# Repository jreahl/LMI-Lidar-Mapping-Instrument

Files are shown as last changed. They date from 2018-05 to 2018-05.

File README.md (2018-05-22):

# LMI-Lidar-Mapping-Instrument
A three-dimensional LIDAR scanner built as part of ASTR 202 in Spring 2018 (Wellesley College). 
LMI was built as a scientific instrument on the Scanning Outcrop Rover (ScOut), which is a semi-autonomous, radio-enabled, path-finding rover. ScOut was built in order to explore a bedrock outcrop in the Wellesley Hinterlands, located just west of Lake Waban in Wellesley, Massachusetts. The Rover had two primary scientific objectives: to construct a three-dimensional map of a bedrock outcrop and to collect images of the outcrop surface. The data from the LMI were used to interpret an environment and to create a DEM (digital elevation model) for the path-finding algorithm.

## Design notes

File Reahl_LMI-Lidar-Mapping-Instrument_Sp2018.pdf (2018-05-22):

## LMI: The Lidar Mapping Instrument

Jocelyn Reahl ‘19

ASTR 202: Hands-On Planetary Exploration

May 22, 2018

Prof. Wes Watters

Abstract

The Scanning Outcrop Rover (ScOut) is a semi-autonomous, radio-enabled, path-finding rover that was built during the Spring 2018 semester. ScOut was built in order to explore a bedrock outcrop in the Wellesley Hinterlands, located just west of Lake Waban in Wellesley, Massachusetts. ScOut had two primary scientific objectives: to construct a three-dimensional map of a bedrock outcrop and to collect images of the outcrop surface. Due to time constraints, ScOut was not fully constructed by the end of the semester. However, individual components of this rover were partially or fully complete by the end of this project. This paper focuses on one of the two scientific instruments: the Lidar Mapping Instrument (LMI; pronounced “Lemmy”). LMI constructed a three-dimensional point cloud map using a specialized Lidar scanning mount. These data were used to: 1) interpret an environment and 2) to create a DEM (digital elevation model) for the path-finding algorithm.

## Introduction

Lidar, an acronym for Light Detection and Ranging, is an active form of remote sensing where information about an object is obtained from a signal sent by a transmitter that reflects off of the object and is received back at the source. While there are many types of Lidar, the most common and commercially available Lidar is topographic Lidar, also known as Laser Altimetry for airborne applications. Topographic Lidar sensors use near-infrared (NIR) light in the form of a pulsed laser to measure distances of objects relative to the sensor. These sensors employ the following time-of-flight (ToF) equation to determine the distance D that the object is away from the sensor:

D = tc
2 | (1)

Where t is the elapsed time between sending the laser pulse and recording the backscattered signal, and c is the speed of light (3.0 x 10⁸ m s⁻¹
).
LMI’s Lidar sensor is Garmin’s Lidar Lite v3, which uses a Class 1 NIR laser to measure the distances of objects at a range of up to 40 meters. In LMI’s case, the LIDAR Lite v3 works on an I²C bus under the control of an Arduino Nano microcontroller. A hookup guide for this sensor is available on SparkFun’s website. Finally, the Lidar Lite v3 operates on the Arduino IDE using Garmin’s LIDARLite library (available on GitHub).

This sensor is only able to measure distances; therefore, it is unable to independently construct a three-dimensional point cloud map. In order to construct a map, LMI records three variables in order to record a Lidar measurement in a spherical coordinate system: distance D, azimuth angle q, and altitude angle f. q and f are known using two servo motors, hereby referred to as the azimuth and altitude motors, respectively. A diagram of the relationship between the spherical and Cartesian coordinate systems is shown in Figure 1, and the following equations are used to convert spherical coordinates into Cartesian coordinates:

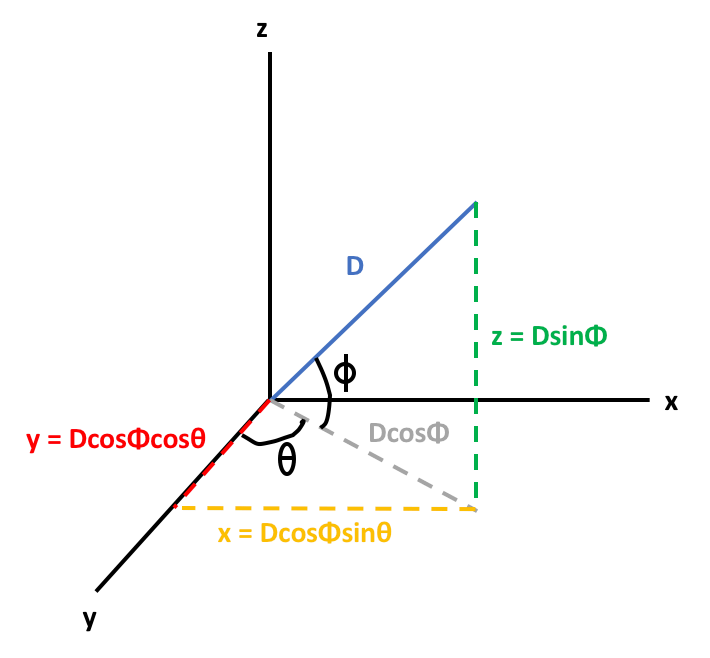
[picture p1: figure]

Figure 1. Diagram of the relationship between spherical and Cartesian coordinates.

x = Dcosφsinθ
y = Dcosφcosθ | (2)
z = Dsinφ

LMI was also meant to be equipped with SparkFun’s MPU 6050 (developed by InvenSense) and SparkFun’s MAG 3110 Triple Axis Magnetometer. However, there was not enough time to integrate these sensors into LMI.

## Instrument Description

LMI uses the following electronic parts: the Lidar Lite v3, a 680 µF capacitor, one standard size servo motor (azimuth servo), one 8 g mini servo motor (altitude servo), an Arduino Nano, a ¼ size Adafruit protoboard, a ½ size Adafruit protoboard, and a 6-wire slip ring. The 6-wire slip ring prevents rotating wires from tangling and disconnecting. The 680 µF capacitor is recommended by Garmin and makes it easier for the Lidar sensor to make measurements. There is room available on the ½ size protoboard to install the MPU 6050 and MAG 3110 sensors in future iterations of this project. There are three male header pins located on the ¼ and ½ size protoboards that accommodate female servo headers. There is also a male header pin soldered to pin A0 on the ½ size protoboard that allows for Parallax Feedback 360°™ functionality. Figure 2 shows a Fritzing diagram of the LMI circuit.
LMI’s Lidar Lite v3 sensor uses a Class 1 NIR laser with a nominal wavelength of 905 nm and an 8 mRadian beam divergence to measure the distances of objects at a range of up to 40 meters. The sensor has an accuracy of ± 2.5 cm between 2 and 5 meters and an accuracy of ± 10 cm at greater than 5 meters. The sensor is able to sample 270 times per second and operates under an I

2
C or pulse width modulation (PWM) interface at a voltage between 4.5 and 6 volts. More information on this sensor can be found in Garmin’s Lidar Lite v3 Manual.

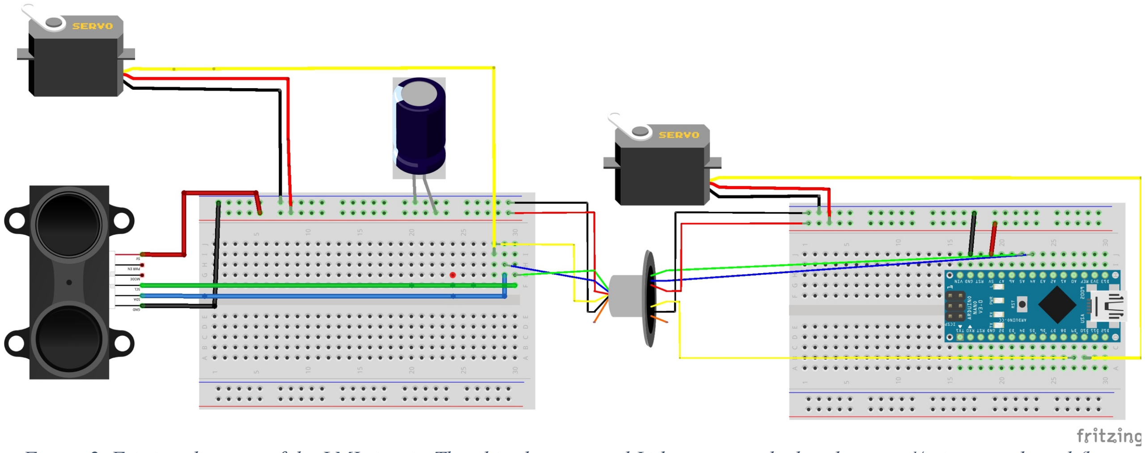
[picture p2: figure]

Figure 2. Fritzing diagram of the LMI circuit. The altitude servo and Lidar are attached to the same ¼ size protoboard (here represented as a ½ size breadboard) with a 680 µF capacitor. The connections on the ¼ size protoboard are then connected to the 6 wire slip ring. The wires from this slip ring are then connected to the Arduino Nano. The azimuth servo is directly connected to the Arduino at digital pin 9 (D9) while the altitude servo is connected via the slip ring at digital pin 10 (D10). The Lidar’s SDA and SCL wires (blue and green, respectively) are connected to the Nano’s analog pins 4 (A4) and 5 (A5), respectively.
The LMI mount was constructed using a combination of laser-cut pieces of plywood and delrin, 3D printed parts, and hot glue. These parts can be found in a variety of formats (SolidWorks, DXF, CDR, and STL) at this project’s associated GitHub repository. Figure 3 shows pictures of the mount assembly and 3D printed parts in SolidWorks. Figure 4 is a photograph of the completed LMI assembly.
The 3D printed parts were printed in Clapp Library’s MakerLab. There were three 3D printed parts: the sensor mount, which secures the Lidar Lite v3 and ¼ size protoboard using screws; the bracket, which suspends the sensor mount in the air and serves as the location where the altitude servo is held in place, and the wirefeed, which allows the gear below the bracket to securely rotate in place while allowing for wires from the slip ring to pass through into the housing’s interior.
The main mount housing was built with laser-cut plywood pieces. Every piece of the housing was held together with hot glue with the exception of the mount base, which was screwed into place. The screws were used to facilitate easy removal and access into the housing’s interior. There are three openings on the housing: a place for the 3D printed wirefeed piece; a place to install a standard-size servo motor; and a place to plug in the micro USB for the Arduino Nano. The wirefeed was hot glued with the gear attached onto the housing. The gears used to rotate the Lidar sensor in the azimuth direction were laser cut out of ¼” white delrin. The bracket was secured to a bracket mount (which was also laser cut and hot glued to a gear) using six screws.

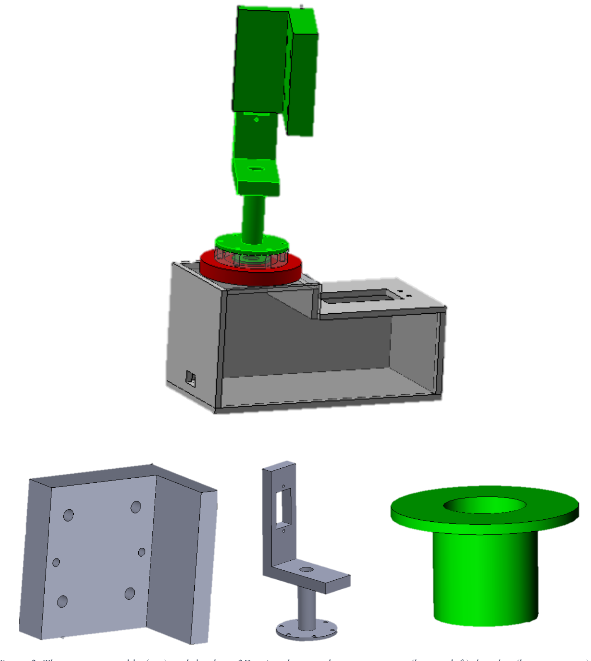
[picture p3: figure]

Figure 3. The mount assembly (top) and the three 3D printed parts: the sensor mount (bottom left), bracket (bottom center), and wirefeed (bottom right).

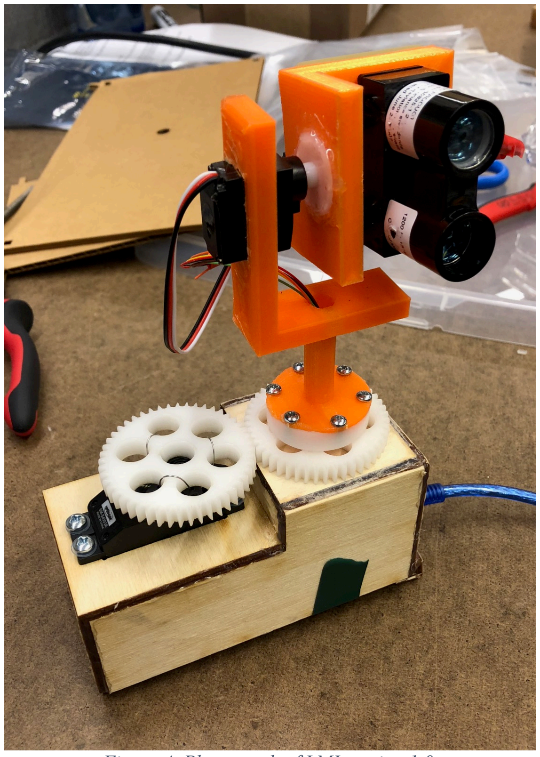
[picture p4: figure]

Figure 4. Photograph of LMI version 1.0.

## Code

The scripts used to operate LMI can be found on this project’s GitHub repository. LMI.ino runs on the Arduino IDE while LidarViewer.pde (by Charles Grassin) runs on Processing. LMI.ino is based on a template called LidarTurret.ino by Charles Grassin, which is also included in the repository. The links to the libraries used in these programs (Servo, LIDARLite, and Wire) can be found in the References section of this paper. To plot LMI’s data, we used Wes Watter’s (2018) cloudplot.py, which constructed not only point cloud maps but also constructed a digital elevation model (DEM) that can be applied to the path-finding algorithm.

## Process and Log

The following is a more streamlined version of LMI’s project log. An informal version, written in bullet point format, can be found as a PDF on this project’s GitHub repository.

1. Received the Lidar Lite v3, MAG 3110 (magnetometer), and MPU 6050 (IMU) from SparkFun and began research on operating specifications. Ordered an Arduino Nano from Amazon.com.

2. Downloaded the Arduino IDE from the Arduino website with the help of a SparkFun tutorial. Also downloaded FTDI drivers so that my Mac OS X High Sierra operating system can use the Arduino IDE.
3. Made my first Arduino circuit using the Lidar Lite v3 Hookup Guide from SparkFun with the following circuit diagram:

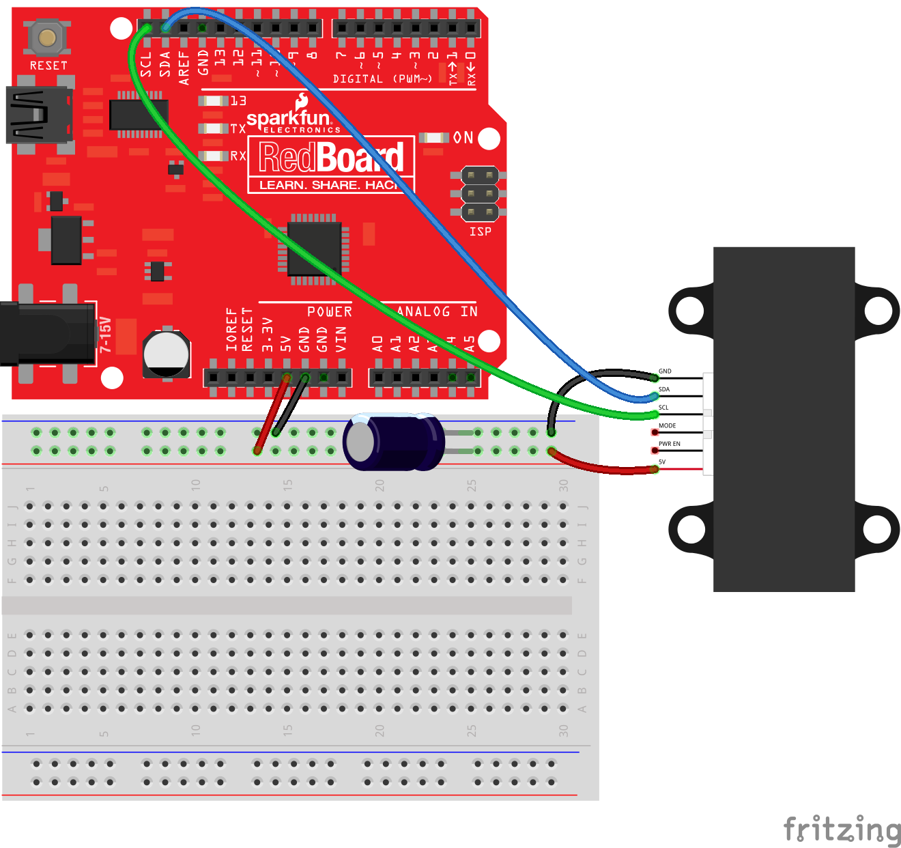
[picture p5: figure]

4. Investigated SLAM algorithms and determined that applying this algorithm would be too complex for the scope of this project. With that being said, it would be interesting to apply these to this instrument in the future.
5. Learned about a program called SlugView, which is a free point cloud analysis software on OpenTopography. However, for our purposes, we realized that using a Python script would also plot our point clouds.
6. Learned about the differences between stepper and servo motors and came to the conclusion that servo motors would be easier to use than stepper motors.
7. Received Arduino Nano from Amazon, but after endless troubleshooting with my computer I realized that the Nano was a clone. In the end I purchased another Nano from the Arduino website.
8. Learned how to solder and began working with the MPU 6050. However, I realized that it wasn’t working given everything that I had tried. Future iterations of this project should investigate how to implement the MPU 6050 into this scanner. Successfully programmed the MAG 3110 but determined that it wouldn’t have much use without the MPU 6050.
9. Ordered a slip ring, continuous rotation servo, Parallax Feedback 360°™ servo, and mini servo.
10. Received all of the previously ordered products and constructed the first LMI prototypes.
11. Designed mount housing in SolidWorks.
12. Laser-cut and 3D printed housing components.
13. Constructed LMI v. 1.0 while simultaneously soldering circuit together on ¼ and ½ size protoboards.
14. Created a scan of the WeLab and of the Outdoor Classroom by the Observatory.

## Preliminary Data

Since the LMI was not installed on the rover, it did not collect data during a “drive” around an outcrop; there was simply not enough time to integrate all of the individual components into the rover. However, LMI was able to complete a trial scan of Wellesley’s Outdoor Classroom, which is located just outside of the Observatory. This location was chosen because it was: 1) nearby and easily accessible, 2) had interesting structures in the field of view (e.g. a tree, a slope), and 3) had randomly distributed rocks that could be used as a proxy for obstacles.
The full scan swept 0 to 75° in f (altitude) and 0 to 180° in q (azimuth). The scan took 25 minutes to complete one whole sweep. The plotted point cloud and DEM are shown in Figure 5. Both plots were created using cloudplot.py (by Wes Watters (2018), available in the repository). All point data recorded as of 5/22/2018, including Test 3 b (the data plotted in Figure 5) are also available in the repository.

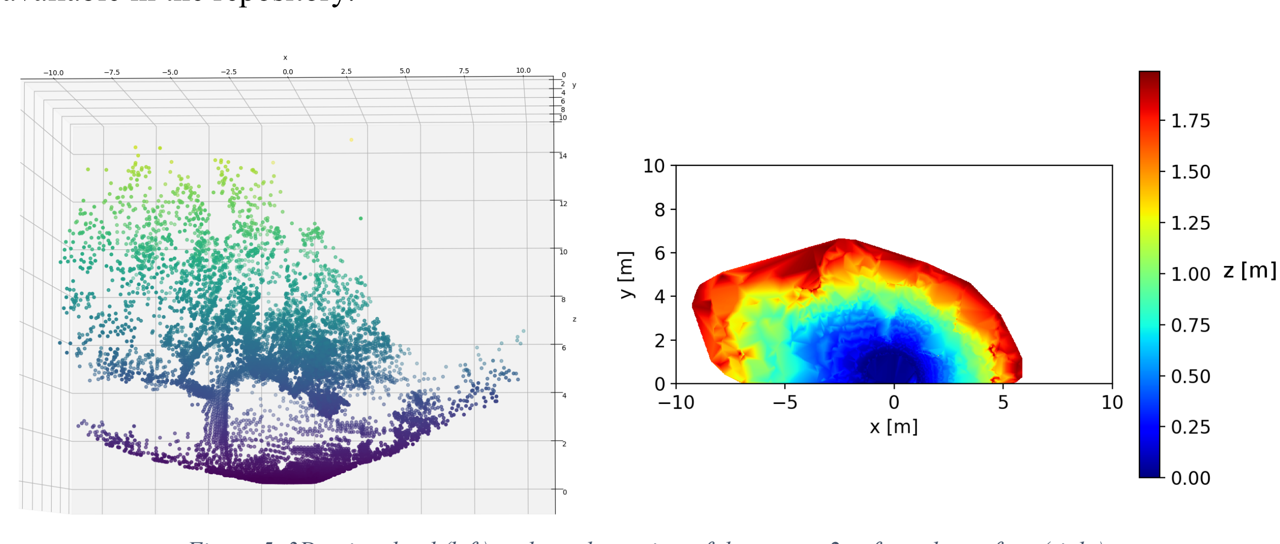
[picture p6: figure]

Figure 5. 3D point cloud (left) and top-down view of the scan < 2 m from the surface (right).

## Discussion and Future Paths

The LMI was able to successfully make multiple scans of both indoor and outdoor structures (the plots in Figure 4 are only one of many more scans). However, the LMI needs to take data during a rover drive. In order to get closer to achieving this goal, future workers need to perform the following tasks, in order of priority:
1. Set up communication between ScOut’s Rasberry Pi and LMI’s Arduino Nano. The Nano should be sending LMI data directly to the RasPi either as a stream of data from the Serial Monitor or as a text (.txt) file that is compiled on the Nano and then sent to the RasPi for processing. This communication also involves setting up the Pi to tell the Nano when to start and stop scans.
2. Implementing the inertial measurement unit (IMU; sensor: MPU 6050) and the magnetometer (sensor: MAG 3110) into the LMI circuit on the ½ size protoboard. The MAG 3110 would operate under the control of the MPU 6050, and the MPU 6050 would send acceleration, gyroscope, orientation, and magnetic bearing data to the Arduino

Nano, which would then be sent to the RasPi. These data act as calibrations that would allow the map to be properly rendered and oriented after multiple scans. Although we were able to get the MAG 3110 to work (using the SparkFun MAG 3110 Magnetometer Breakout Library), we were unable to get the MPU 6050 working after multiple attempts. Links to “starting points” for the MPU 6050 in the form of Arduino forum posts and
I

2Cdev forums can be found in the References section. The issue might potentially lie in how the Arduino addresses the sensor (0 x 68 versus 0 x 69), and there might be a way to easily fix this in Jeff Rowberg’s example code from his MPU 6050 library.
- It is important to note that we were able to control the MAG 3110 sensor independently of the MPU 6050; the final iteration of the MAG 3110 sensor needs to be connected to the MPU 6050. This is another challenge.
- The MAG 3110 also needs to be programmed to record magnetic bearings (e.g. programmed as a compass) instead of raw magnetic field data.
- If the MPU 6050 is a bust, an ADXL 3xx three-axis accelerometer sensor in combination with a three-axis gyroscope sensor would be an acceptable replacement.
3. Implementing the Parallax Feedback 360°™ continuous rotation servo onto the LMI. This servo allows 360° azimuth rotation while simultaneously providing position feedback. This not only allows for full 360° views of the rover’s surroundings, but it would in theory allow our Arduino program to tell the servo (and thereby the Lidar sensor) to move to a specific position that is determined by the direction of the magnetic bearing provided by the MAG 3110 sensor. However, this servo does not have much documentation related to Arduino, as documentation from the website is written in Java. Some Arduino users like JavelinPoint have created code to run this servo, but it relies on PID control and is difficult to use. LMI has an extra header installed at pin A0 in order to allow for easy Parallax Feedback 360°™ installation and use with JavelinPoint’s code.
- An alternative is implementing a stepper motor with a full step size of 0.9°. The advantage of this motor is that it can be programmed to move in smaller than 1 degree increments of q. However, the motor does not provide position feedback unless it has an encoder.
4. Improving the LMI housing and stability, which includes but is not limited to:
- 3D printing the main mount housing (this housing is currently made out of plywood)
- Using wood-joinery techniques to put housing pieces together instead of hot glue.
- Shifting the Lidar sensor position on the altitude servo so that the sensor can move freely from 0 to 180° in altitude (assuming that the Parallax Feedback 360°™ servo or a stepper motor cannot be installed with LMI)
- Purchasing a longer micro-USB to USB cable that can both charge and transmit data. The previously purchased cable is not the right size micro-USB for the Nano.
- Creating more secure wire connections that can still be taken apart (ex. if the LMI needs to be taken apart piece by piece). The current setup has the electronic wiring and the physical mount deeply intertwined; pieces of the physical mount cannot be removed without removing the wires, and vice versa.

## References

LMI GitHub Repository
Reahl, J. LMI-Lidar-Mapping-Instrument, GitHub, accessed May 22, 2018, https://github.com/jreahl/LMI-Lidar-Mapping-Instrument.

Lidar Background
“What is LIDAR?” NOAA, https://oceanservice.noaa.gov/facts/lidar.html.
Corrigan, Fintan. “12 Top LIDAR sensors for UAVs and So Many Great Uses,” DroneZon, January 17, 2018, https://www.dronezon.com/learn-about-drones-quadcopters/best-lidarsensors-for-drones-great-uses-for-lidar-sensors/.
Cameron, Oliver. “An Introduction to LIDAR: The Key Self-Driving Car Sensor,” Voyage, May 9, 2017, https://news.voyage.auto/an-introduction-to-lidar-the-key-self-driving-carsensor-a7e405590cff.
NEON Science. “How Does LiDAR Remote Sensing Work? Light Detection and Ranging,” Youtube, November 24, 2014, https://www.youtube.com/watch?v=EYbhNSUnIdU. Marcoe, K. “LIDAR: an Introduction and Overview,” Portland State University, Fall 2007, http://web.pdx.edu/~jduh/courses/Archive/geog481w07/Students/Marcoe_LiDAR.pdf.

Lidar Mount Examples
TechsOnTube. “LIDAR-Lite v3 – 3D-Scan,” Youtube, November 9, 2016, https://www.youtube.com/watch?v=gCpCGkwwy8I.
Guy, A. “LIDAR Sensor – 3D Printed Rotating Platform – Robotic Vehicle #8,” Youtube, March 10, 2017, https://www.youtube.com/watch?v=RHPAJ3kjc3Q.
Guy, A. “Rotating 360 LIDAR Scanner – 3D Printed up and down scanning – Robotic Vehicle #9,” Youtube, May 6, 2017, https://www.youtube.com/watch?v=zizrY-cOS9k.
Grau, A. “DIY 360 DEGREE REALTIME OUTDOOR LIDAR WITH ROS SUPPORT (GRAULIDAR),” Don’t worry be creative, 2015, http://grauonline.de/wordpress/?page_id=1233.
Grassin, C. “3D LIDAR SCANNER,” Charles’ Labs, October 10, 2017, http://www.charleslabs.fr/en/project-3D+Lidar+Scanner.

Product Pages
Garmin Lidar Lite v3, SparkFun, https://www.sparkfun.com/products/14032. SparkFun Triple Axis Accelerometer and Gyro Breakout – MPU-6050, SparkFun, https://www.sparkfun.com/products/11028.
SparkFun Triple Axis Magnetometer Breakout – MAG3110, SparkFun, https://www.sparkfun.com/products/12670.
Arduino Nano, Arduino, https://store.arduino.cc/usa/arduino-nano. Adafruit Perma-Proto Quarter-sized Breadboard PCB – 3 Pack!, Adafruit, https://www.adafruit.com/product/589.
Adafruit Perma-Proto Half-sized Breadboard PCB – 3 Pack!, Adafruit, https://www.adafruit.com/product/571.
Slip Ring with Flange – 22mm diameter, 6 wires, max 240 V @ 2A, Adafruit, https://www.adafruit.com/product/736.
Servo – Generic (Sub-Micro Size), SparkFun, https://www.sparkfun.com/products/9065.

Servo – Generic High Torque Continuous Rotation (Standard Size), SparkFun, https://www.sparkfun.com/products/9347.
Servo – Generic High Torque (Standard Size), Sparkfun, https://www.sparkfun.com/products/11965.
Parallax Feedback 360° High Speed Servo, Parallax Inc., https://www.parallax.com/product/900-00360.

Software
Arduino Libraries. Servo Library for Arduino, GitHub, accessed May 22, 2018, https://github.com/arduino-libraries/Servo.
ESP8266 Community Forum. Wire.h, GitHub, accessed May 22, 2018, https://github.com/esp8266/Arduino/tree/master/libraries/Wire.
Garmin International. LIDAR-Lite v3 Arduino Library, GitHub, accessed May 22, 2018, https://github.com/garmin/LIDARLite_v3_Arduino_Library.
Arduino IDE 1.8.5, Arduino, https://www.arduino.cc/en/Main/Software.
Processing 3.3.7, Processing, https://processing.org/download/.
Rowberg, J. MPU 6050 Arduino Library, GitHub, accessed May 22, 2018, https://github.com/jrowberg/i2cdevlib/tree/master/Arduino/MPU6050.
SparkFun Electronics. SparkFun MAG3110 Breakout Board Arduino Library, GitHub, accessed May 22, 2018,
https://github.com/sparkfun/SparkFun_MAG3110_Breakout_Board_Arduino_Library. Fritzing 0.9.3b, Fritzing, http://fritzing.org/download/.
I2CScanner, Arduino,
https://playground.arduino.cc/Main/I2cScanner?action=sourceblock&num=1. Grassin, C. LidarTurret.ino, Charles’ Labs, October 10, 2017, http://www.charleslabs.fr/en/project-3D+Lidar+Scanner.
Grassin, C. LidarViewer.pde, Charles’ Labs, October 10, 2017, http://www.charleslabs.fr/en/project-3D+Lidar+Scanner.

LIDAR Lite v3
“Lidar Lite v3 Operation Manual and Technical Specifications,” Garmin International, https://static.garmin.com/pumac/LIDAR_Lite_v3_Operation_Manual_and_Technical_Specificat ions.pdf.

MPU 6050
“MPU-6000 and MPU-6050 Product Specification Revision 3.4,” InvenSense Inc., August 19, 2013, http://43zrtwysvxb2gf29r5o0athu.wpengine.netdna-cdn.com/wpcontent/uploads/2015/02/MPU-6000-Datasheet1.pdf.
“Arduino Playground: MPU-6050 Accelerometer + Gyro,” Arduino, https://playground.arduino.cc/Main/MPU-6050#intro.
Sanjeev, A. “How to Interface Arduino and the MPU 6050 Sensor,” Maker Pro Beta, https://maker.pro/arduino/tutorial/how-to-interface-arduino-and-the-mpu-6050-sensor. Arduino Forum Topic: mpu6050 problem, Arduino, thread started January 13, 2013, http://forum.arduino.cc/index.php?topic=142490.0.

Arduino Forum Topic: Easily Changing I2C Address Of MPU6050 Accelerometer + Gyroscope, Arduino, thread started July 14, 2014, https://forum.arduino.cc/index.php?topic=255033.0.
Rowberg, J. “MPU-6050 6-axis accelerometer/gyroscope,” I

2Cdevlib,
https://www.i2cdevlib.com/devices/mpu6050#help.
“Wiring the MPU 6050 Sensor Mems Accelerometer GYRO,” 14Core, http://www.14core.com/wiring-the-mpu-6050-sensor-accelerometer-gyro-with-nano/.

Parallax Feedback 360°™
Arduino Forum Topic: Controlling Parallax Servo 360 in a certain angle, Arduino, thread started December 13, 2017, https://forum.arduino.cc/index.php?topic=516986.0.

Tutorials
b_e_n. “Installing Arduino IDE,” SparkFun, https://learn.sparkfun.com/tutorials/installingarduino-ide.
Smith, P. “How to Install FTDI Drivers: Mac,” SparkFun, https://learn.sparkfun.com/tutorials/how-to-install-ftdi-drivers/mac.
Hymel, S. “LIDAR-Lite v3 Hookup Guide,” SparkFun, https://learn.sparkfun.com/tutorials/lidar-lite-v3-hookup-guide.
b_e_n. “What is an Arduino?” SparkFun, https://learn.sparkfun.com/tutorials/what-is-anarduino.

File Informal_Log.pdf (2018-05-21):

3/16/2018
- Got the LIDAR-Lite v3 sensor! Hooray! (Also got the MPU-6050 (Accelerometer/Gyroscope) breakout board and the MAG-3110 (Magnetometer) breakout board)
- Catherine is letting me use her Arduino until I can get an Arduino of my own
- I NEED TO ORDER AN ARDUINO (either a nano or an uno; probably an uno tbh but we’ll see)
- Verified that the LIDAR-Lite v3 does the following:
- Does NOT have an attached accelerometer or gyroscope (hence why we needed that accelerometer)
- Uses an I2C or PWM Interface (we’ll be running I2C on an Arduino; it’s what the other sensors use, too)
- Only measures distance measures using a ToF (Time of Flight) measurement: (time between sending signal and receiving) * (speed of light)/2
■ Does nothing else, that’s it’s data format
- Comes with a lovely set of rainbow wires that have their own uses:
■ Red = power source (AREF port)
■ Orange = Power enable (Internal pull-up)
■ Yellow = Mode control
■ Green = I2C SCL
■ Blue = I2C SDA
■ Black = Ground (-) (GND)
- Made a “LIDAR-Lite v3 Safety and Warranty Considerations” doc
- Planning on using this as a non-paper reference for warranty info, and also as a safety reference for eventual “Safety and Booting Protocols” related to the LIDAR sensor
- Main safety takeaways:
■ The sensor uses a Class 1 laser, meaning that it’s safe to look at but we really shouldn’t look directly into where the laser is coming from while it’s on
■ We need to turn it off when we’re not using it, to minimize the risk of hurting our eyes
- Learned what SDA and SCL stands for, and how that relates to I2C format
- Have read to the “Settings” subheading in the “Operational Information” section of the LIDAR-Lite v3 Operator’s Manual
- Need to read further
- Uploaded LIDAR-Lite v3 Operator’s Manual PDF into LIDAR folder in Rover Team Drive
- Uploaded I2C Specifications (version 2.1, January 2000, Phillips) into LIDAR folder
- Downloaded Arduino IDE onto Mac running MacOS High Sierra (v10.13.3) using SparkFun tutorial (https://learn.sparkfun.com/tutorials/installing-arduino-ide) and downloaded Arduino IDE from Arduino website (https://www.arduino.cc/en/Main/Software)

- Downloaded FTDI USB Serial drivers (so I can actually run an Arduino on my Mac) from SparkFun (see following link: https://learn.sparkfun.com/tutorials/how-to-install-ftdi-drivers/mac)
- Successfully downloaded FTDI drivers!
- Had an issue where I thought that the FTDI drivers weren’t working, but it turned out that the USB switch power cable that I was using to connect my USB power + data cable was just giving my computer a power input, which was not what I wanted if I wanted to code on the Arduino
- Successfully communicated with the Arduino using the “Blink” Example (File > Examples > 1. Basics > Blink)!

3/20/2018:
- Got two 680µF capacitors yesterday from Chloe, so no worries about ordering these capacitors
- We’ll be applying these capacitors to our intro LIDAR sensing circuit
- Set up LIDAR circuit according to the below configuration:
- IT WORKED, WE GOT DISTANCE MEASUREMENTS!!! Easy peasy

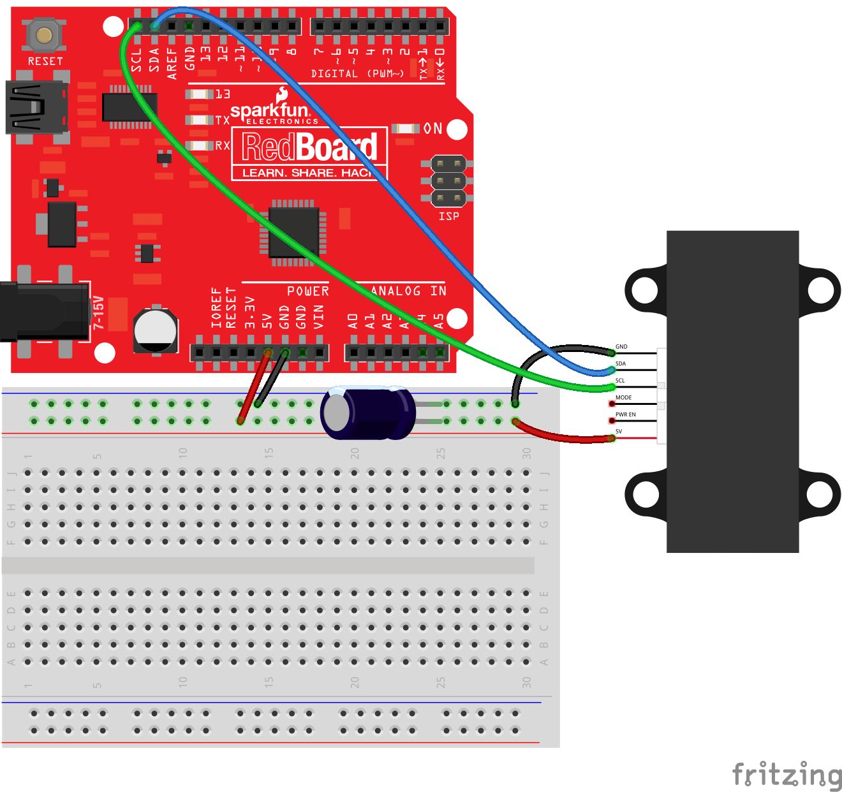
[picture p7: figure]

- Started looking into how we’re gonna visualize these point data using a program
- Questions asked:
■ How do we get these measurements in xyz? Do we use the IMU? ■ How do we take these converted xyz data and turn them into a point cloud?
■ How will these data be used to influence the rover’s movements?
- Started looking into SLAM (Simultaneous Localization and Mapping) algorithms and learning about that
- Realized that just relying on the altitude and azimuth angles relative to a starting point are not gonna be enough if we want to determine xyz points WHILE WE’RE ALSO MOVING BETWEEN MEASUREMENT LOCATIONS (which is why we’re looking into SLAM)

- 3D SLAM algorithms seem to be developing (but compared to 2D versions it seems a little more basic)
- Learned that we’re gonna want to hook up are IMU to be moving with the sensor so we know where the sensor is in 3D space when it’s scanning, which we can then use to determine where the measured data points are relative to the scanner (we’re still looking into SLAM because SLAM allows us to cleanly integrate the scanned map into one cohesive map, instead of individual maps taken at different points that we would then need to blend together, which could end up going horribly wrong especially if we don’t know the scanned area)
- Watched the following videos:
- https://www.youtube.com/watch?v=OJNNm6iMOKk - hour-long talk that gives a really good overview of LIDAR in terms of self-driving robots (which is very necessary for Elif’s part of the project)
■ Also provided info on SLAM and how to plot point clouds
- https://www.youtube.com/watch?v=RHPAJ3kjc3Q - some guy’s first version of a 360° scanning mount, which is good because he actually discusses the pros and cons of this mount; however, he doesn’t show what data is coming from it, and how he might program that
■ Interestingly he uses a reflectance sensor in order to reset the scanner to a starting position, but it means that it doesn’t scan very smoothly :(
■ This version with gears is LOUD
■ Slip rings are IMPORTANT if we want this thing to work at all
- https://www.youtube.com/watch?v=zizrY-cOS9k - the same guy’s second version of his 360° scanning mount, but this time with a weird servo add on so it can go up and down as well as spin in 360° (that being said it didn’t get that much movement so who’s to say how effective it really was)
■ He switches from gears to a timed belt system, which is a heck of a lot smoother and less noisy (and the same kind as used in this more showy, but less useful video: https://www.youtube.com/watch?v=gCpCGkwwy8I) ■ Servo is very awkward because it’s moving the whole platform up and down
■ The whole thing is jumping around a lot because it’s resetting to a known location using the reflectance sensor at every rotation, so it stops and starts again

3/21/2018:
- Found an interesting and free point cloud analysis software called SlugView (“Slug” because it’s from UC Santa Cruz - go Banana Slugs!) that’s listed on OpenTopography, which is a NSF-funded data facility that is available to support PI’s and projects that use lidar
- Link to OpenTopography: http://www.opentopography.org/
- Link to OpenTopography Tools webpage, which includes SlugView: http://opentopo.sdsc.edu/tools/listTools

■ OpenTopography SlugView description: http://opentopo.sdsc.edu/tools/viewTool?toolId=613
- SlugView Description: “This is a Point Cloud visualization tool developed in conjunction with the University of Santa Cruz. SlugView started out as a general point cloud viewer. Neva Ridge Technologies added numerous capabilities primarily to support visualization of point clouds with associated numeric attributes. The data can have up to 2 associated attributes which can be used to control which points are actually displayed. Multiple point clouds can be displayed at once and can be displayed sequentially as an animation. Input data formats are primarily text files. Each line in the text file would contain X, Y, Z and optionally red, green, blue, and additional attribute values.”
- Windows, Mac, and Linux operating systems (needs Java 8, Open GL)
- Manual is listed here:
https://websites.pmc.ucsc.edu/~seisweb/SlugView/manual/manual .html (https://websites.pmc.ucsc.edu/~seisweb/SlugView/manual/manual.html)
- Looks like SlugView can be run in the CLI or in MATLAB, at least according to the manual
- SlugView download and project page: https://websites.pmc.ucsc.edu/~seisweb/SlugView/Slugview.html
- While scrolling through OpenTopography’s website, I found that they hold workshops (which I can’t attend) on how to use lidar and other 3D mapping technologies. This was important because it introduced me to a new potential fix to our 3D mapping issue if we’re given multiple pieces of data at different positions around something: Structure from Motion (SfM)
- SfM is “a photogrammetric range imaging technique for estimating three-dimensional structures from two-dimensional image sequences that may be coupled with local motion signals” (https://en.wikipedia.org/wiki/Structure_from_motion)
■ “Local motion signals” could maybe be acquired through an accelerometer or IMU unit located on the rover body
- Only seems to be a thing for images, so we could potentially apply it to stereo cameras on mast and then the 3D images could be mapped over LIDAR scans, but it doesn’t seem to be relevant to LIDAR point clouds
- Looked into the differences between Stepper and Servo motors:
- Servo motors would allow us to smoothly move over a specific distance (in degrees if we’re using a rotational actuator), and then to return to a home position, and repeat that same thing
■ Typically these move in 180°-ish degrees, but you can buy special ones for 360° motion

■ Controlled with a specific type of pulse train signal: pulses occur at 20mSec (50 Hz) interval, and vary between 1 and 2 mSec in width. Uses PWM (Pulse Width Modulation) hardware (found on many microcontrollers); @ center of mechanical range when pulse = 1.5 mSec ■ Has low RPM (60 RPM max) so stepping motors are better for discrete movements (ie. alt movement on our LIDAR sensor)
■ Used this video to get an understanding of what a servo motor is (Titled “Servo Basic Concepts” from Yasakawa America’s Youtube Channel): https://www.youtube.com/watch?v=t0dSaugIXF8
- This explanation was albeit for industrial users but its still informative for the basic process, and distinguishes between linear and rotational actuators
■ This video (“Electronic Basics #25: Servos and How to Use Them” GreatScott!) is a bit more accessible for someone who’s only planning on using tiny, cheap servos for my project: https://www.youtube.com/watch?v=J8atdmEqZsc
■ Needs a driver to run
■ Have a three-pin plug: ground, voltage, and the command line (pin colors are not consistent across servos, so need to check documentation)
- Stepper motors can easily move in 360° and can easily move at specific degree increments
■ Looked at this video (“Electronic Basics #24: Stepper Motors and How to Use Them” GreatScott!) to get a sense for stepper motors and how to use them: https://www.youtube.com/watch?v=bkqoKWP4Oy4
■ Can be combined with a timing belt to get really smooth motion
■ Needs a driver to run, which can be purchased on SparkFun
■ While you can buy steppers that have 200 or 400 steps per rotation, you can increase the number of steps by half-stepping or micro-stepping which gives you less torque as you increase the number of steps
- In my endless search to figure out my xyz points given just a distance measurement, I decided to look into how I might get these data
- Originally I’m thinking that I should use an IMU sensor that’s actually moving with the moving sensor so that we get acceleration and gyroscope data

4/6/2018:
- Ok so since writing in this last I have:
- Received an Arduino Nano, but upon closer inspection it might be a clone
- Written a detailed update to the LIDAR section of my proposal
■ Compiled scan time estimates assuming the sweep of phi = 45 degrees ■ Figured out calculating relative distance using a reference point
■ Figured out how to calculate xyz points given theta, phi, and distance data ■ All this is effectively written in the proposal
- Still having issues getting Arduino Nano to upload a code

- Downloaded another FTIR driver for Mac (v. 2.4.2) - didn’t work
- Consulted forums - didn’t give me progress
- In exasperation I tried running the Blink example (Arduino > File > Examples > 1. Basics > Blink) on the original Uno that Catherine gave me, and I got the following error:
- /Users/jocelynreahl/Library/Arduino15/packages/arduino/tools/avr-gcc/4.9.2-atme l3.5.4-arduino2/bin/avr-g++: no such file or directory
- Decided to uninstall Arduino software in an attempt to fix it because I couldn’t find the Arduino15 file in the Library on my computer (Macbook Pro running OS X High Sierra)
- Wes and I tried doing a bunch of stuff on the terminal and it… didn’t work. None of it worked
- Started to give up and log into a computer running Windows 7 to try downloading Arduino IDE on it, but realized that when I originally uninstalled the Arduino IDE, I forgot to delete the hidden Arduino15 file in Library
- Had Wes delete it before I redownloaded the new IDE, and IT WORKED HOLY CRAP
■ By “it worked” I mean that the UNO is working on it again; the nano (which I’m certain is a clone now) still isn’t working
- Tried downloading Arduino IDE on classroom computer, and it wouldn’t let me unless I was an admin, so in theory I could log in under Wes’s profile, but that starts getting into some weird territory that requires a lot of effort on both ends
- Ended up just having Jenny get an original Nano from the Arduino website, because nothing seems to be working and the following forum post implies that even if I did install the correct drivers for the clone, it still wouldn’t work on Mac OS Sierra and above unless I did some crazy troubleshooting that is super time consuming -
https://arduino.stackexchange.com/questions/34775/arduino-nano-not-visible-in-s erial-ports-mac-os (https://arduino.stackexchange.com/questions/34775/arduino-nano-not-visible-in-serial-ports-mac-os)
- Got Jenny to get the Nano from this website: https://store.arduino.cc/usa/arduino-nano

4/10/2018:
Tasks for today (if servo motors AND Nano haven’t arrived yet)
1. Get MPU 6050 and MAG 3110 sensors wired up and running
a. Includes downloading necessary Arduino libraries and reviewing datasheets for each sensor -- Almost done for MPU 6050
b. Also obviously includes getting them wired to a breadboard -- Done for MPU 6050
2. Learn to solder @ WeLab at 11:00am -- Done
Tasks for today (if Nano has arrived but not servo)
1. Same as above
2. Get LIDAR hooked up on Nano

- Pulled up MPU 6050 datasheet (http://43zrtwysvxb2gf29r5o0athu.wpengine.netdna-cdn.com/wp-content/uploads/2015/02/MPU-6000-Datasheet1.pdf) (http://43zrtwysvxb2gf29r5o0athu.wpengine.netdna-cdn.com/wp-content/uploads/2015/02/MPU-6000-Datasheet1.pdf) to start learning about MPU specs:
- Called a 6-axis motion tracking device (ie. 3 axis accelerometer + 3 axis gyroscope + Digital Motion Processor

TM
(DMP))
■ Note that gyroscope is tracking yaw, pitch, and roll (ie. rotational motion), and accelerometer is tracking translational motion in x, y, and z
- Dedicated I

2C bus ⇒ working with Arduino Uno/Nano
- Says that w/a 3 axis “compass” (which I’m reading as a magnetometer for now) you can get a 9-axis MotionFusion

TM output (this is thanks to the DMP)
- Designed to interface w/non-inertial sensors like pressure sensors (and maybe LIDAR sensors, ooooOOOOooo)
- Has 3 16-bit analog-to-digital converters (ADC’s) for digitizing gyroscope outputs and another 3 for digitizing the accelerometer outputs
- Users can program the gyroscope and accelerometer to track fast and slow motion:
■ Gyroscope: ±250, ±500, ±1000, and ±2000°/sec
■ Accelerometer: ±2g, ±4g, ±6g, ±8g and ±16 g
- Low power thanks to 1024 byte FIFO buffer ⇒ allows the system processor to read the MPU data in bursts instead of constantly
- Gyroscope specs (besides user-programmable stuff):
■ Gyroscope operating current: 3.6mA
■ Standby current: 5µA
■ User self-test
- Accelerometer specs (besides user-programmable stuff):
■ Accelerometer normal operating current: 500µA
■ Low power accelerometer mode current: 10µA at 1.25Hz, 20µA at 5Hz, 60µA at 20Hz, 110µA at 40Hz
■ Orientation detection and signaling
■ User-programmable interrupts
■ High-G interrupt
■ User self-test
- General MPU 6050 specs:
■ Auxiliary master I2C bus for reading data from external sensors (e.g., magnetometer)
■ 3.9mA operating current when all 6 motion sensing axes and the DMP are enabled
■ VDD supply voltage range of 2.375V-3.46V
- So apparently there’s a temperature sensor that’s just randomly on here????
- So SparkFun doesn’t have a ton of stuff besides GitHub links, so I’m gonna check the Arduino Playground page on the MPU 6050: https://playground.arduino.cc/Main/MPU-6050#intro

- Reading raw accelerometer and gyroscope values is easy, but getting a magnetometer on there is a little trickier
■ The MPU can act as a slave to the Arduino if it’s connected to the SDA and SCL pins on the Arduino, but the MPU also has its own auxiliary I

2C
pins (called AUX_DA and AUX_CL) for the second (aka sub) I

2C bus
- The following link provided great info on how to set up MPU circuit and how to get the necessary libraries for them: https://maker.pro/education/imu-interfacing-tutorial-get-started-with-arduino-and-the-mpu -6050-sensor (https://maker.pro/education/imu-interfacing-tutorial-get-started-with-arduino-and-the-mpu-6050-sensor)
- Set up circuit, will get code hopefully understood next time (and hopefully servo motors will come by then too

4/12/2018:
Task:
1. Getting the MPU 6050 running w/Arduino example code
2. Getting MAG 3110 library downloaded
3. Maybe getting MAG 3110 running w/Arduino example code if possible
- So I triple checked the circuit for the MPU, but when I tried running the example program it kept telling me that the MPU wasn’t connected, so I’ll be following up this later

4/13/2018:
Before class:
- Was looking into installing MAG 3110 library and I realized that I’ve been installing libraries wrong so I moved all the libraries to the proper location (from “Documents > Arduino > libraries” to “Applications > Arduino > Contents > Java > libraries”)
Tasks are the same as 4/12/2018
- Downloaded MAG 3110 library
- Verified that I have a Servo library and looked at examples
- Spent a LONG time troubleshooting the MPU again:
- Tried reconnecting circuit in 10,000,000 different ways; still getting the error
“MPU 6050 not connected” on Jeff Rowberg’s program
- Soldered headers on MPU 6050 and MAG 3110 in the hope that doing that would fix my problem (one of many forum discussions on Arduino seemed to have soldering do the trick) - didn’t work but hey at least I have headers on my sensors now
- Lots of forums seem to use an Arduino program called I2C scanner that checks for I2C things that are connected, and Meba gave me the link to it - used the I2C scanner (link to code:
https://playground.arduino.cc/Main/I2cScanner?action=sourceblock&num=1) and the MPU isn’t showing up on the scanner, but the MAG is, meaning that it’s either a board or a port issue (forums that mention this: http://forum.arduino.cc/index.php?topic=142490.0;https://forum.arduino.cc/index.php?topic=255033.0)

- Also consulted I2C dev forum on this (written by Jeff Rowberg, who seems to be the guru on the MPU 6050) and it didn’t really have answers for me besides the ones I had originally tried: https://www.i2cdevlib.com/devices/mpu6050#help
- I might have found some code that’s helpful because it actually defines the I2C addresses of each MPU component!
■ Original address:
http://www.14core.com/wiring-the-mpu-6050-sensor-accelerometer-gyro-with-nano/ (http://www.14core.com/wiring-the-mpu-6050-sensor-accelerometer-gyro-with-nano/)
■ Code in this page seems to have been originally written by arduino.cc, but when I googled the name of the code it isn’t showing up with Arduino so who knows what this code’s actually gonna do
- I have a tad bit of hope though because this code has a lot of documentation, defines literally everything, and was originally written by arduino.cc; and also given all of the other written things about this sensor and when they were written (2012-2014ish), the last updates on the code were done in 2013 so it would make sense for it to exist at this point in time, too
- Got the MAG 3110 up and running an example bit of code - Wes wants me to use the xyz measurements of the magnetic field to inform rover placement, but I don’t know how feasible that is and I’m still going to work on the MPU
- Servos arrived! Didn’t get a chance to work with those at all today but I will definitely be doing that this weekend.

4/14/2018:
Tasks:
1. Make a prototype of LIDAR scanner
2. Troubleshoot MPU 6050
- Prioritized Task 1 for today and was working with Meba
- Meba and I downloaded a plan from GrabCAD that’s for a 48 tooth spur gear
- We then edited that plan on Meba’s computer to be laser-cuttable (ie. 2D)
- We then cut out two of these spur gears on ¼” plastic (I forget the exact name of it at this time) - the gears work really well together!
- This was a challenge initially because the computer that we used to do the laser cutting kept saying that it couldn’t cut because there was no COM port to be found; it eventually solved it on its own (I think we just had to be more patient with it)
- Played around with the continuous rotation servo that we bought, and we ran into a problem: the servo doesn’t seem to move very accurately, it only seems to spin
- After a lot of troubleshooting we realized that continuous rotation servos are basically glorified DC motors with no position feedback - might need to purchase a different motor, like maybe a stepper - but for prototyping this isn’t critical just yet

- Managed to build a prototype for the mount that allows the LIDAR scanner to move in azimuth. Altitude will be managed this weekend!

4/15/2018:
Tasks:
1. Investigate stepper motors and potential other solutions to continuous rotation and feedback
- Learned today that not only do continuous rotation servos not provide feedback, but neither do steppers
- So this made me really worried about getting the 360 component to work without calculating the angle theta swept per increment of time, but I learned that there’s a way to get around this problem: an encoder
- Encoders hook up to the back of a motor and basically keep track of where it is
- Learned through further research that a company called Parallax made something called a Feedback 360° servo motor, which is basically a continuous rotation servo motor but with the feedback component that we all know and love
- Link to product page: https://www.parallax.com/product/900-00360
- There are cheaper versions on Amazon for less
- Finding the feedback 360° was cool, but there isn’t a ton of arduino documentation on it
- Found some code by JavelinPoint on an Arduino Forum that apparently gets the job done for both reading position and continuously rotating: https://forum.arduino.cc/index.php?topic=516986.0
- Current plan is to run all this by Wes and see what he thinks - I think he might approve because stepper motors and the continuous rotation motor clearly don’t work without an encoder which is a pain in the ass to get
- So all in all, I would like to purchase the Parallax Feedback 360° servo motor ASAP, and will be emailing Jenny about it soon: https://www.amazon.com/Parallax-Feedback-360%C2%B0-Speed-Servo/dp/B074XKBWJ5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 (https://www.amazon.com/Parallax-Feedback-360%C2%B0-Speed-Servo/dp/B074XKBWJ5)
- Also downloaded Fritzing to begin making my circuit diagrams, but it’s definitely gonna be a learning curve to use this so we’ll see

4/19/2018:
- Began working on prototype code that can have LIDAR running w/servo motors and little breadboard
- Was worried today that maybe we didn’t need the little breadboard, but I just remembered that we also need to connect a 680 µF capacitor to this circuit for the LIDAR so honestly thank god
■ That reminds me, I should double check to see if the servos are gonna be affected if this is in the circuit… probably not, right? - the LIDAR GetDistanceI2C example seems to indicate that it’s just there to mitigate “inrush current” when the sensor is on, whatever the heck that means

- Gonna try getting this code to be pretty comprehensive, so that it’s almost like an example piece of code for anyone working with this in the future
- Planning on including Fritzing diagram in this code, both for future readers’ sake and also my own

4/26/2018:
- Ok so since last writing in here I’ve:
- Started creating parts in SolidWorks that will eventually be 3D Printed/Laser Cut and then assembled (this has been the bulk of my work)
- Started working on Fritzing diagram for the circuit I’m making
- Received the Arduino Nano in the mail! Finally! And I also received the Parallax 360° servo motor, but I haven’t gotten a chance to try coding with it (I am PRAYING that it works and that I don’t have to make a last-minute stepper motor order, because that would be the literal worst)
- Seriously started working on my Arduino code for the instrument, and now I’m considering how it’ll communicate with the Raspi (and I’m also assuming it’s getting its power from it as well, and it’s connected to a power source)
- Haven’t gotten a chance to more troubleshooting on the MPU, which is… concerning

5/2/2018:
- I LASER CUT AND CONSTRUCTED THE HOUSING! I still need to get the 3D printable stuff 3D printed in Clapp, and given all of my other work it’s looking like I would need to do that tomorrow (Thursday)
- I’ve backed up all of my SolidWorks files on a USB as a “just in case” and also as a necessity since my computer doesn’t run solidworks to begin with
- Had a team meeting yesterday with Wes and Jenny, and the major issues with LIDAR that we still have are:
- We still need to construct the housing and 3D printed thing, and get it spinning ■ To “get it spinning” we need to make a decision about the Parallax 360 Servo and whether or not we can get it to work. Jenny has been looking into it but it doesn't seem like it would get done within our block of time, so the new plan for now is to just use the continuous rotation servo and estimate the approximate theta’s covered
- We need to get some kind of accelerometer hooked up, and if it’s not the MPU 6050 then it’ll be an ADXL 343/345 that we hopefully have lying around.

http://www.charleslabs.fr/en/project-3D+Lidar+Scanner
https://processing.org/download/https://arduino.stackexchange.com/questions/1758/whats-the-most-accurate-way-to-time-stamp-analogread-data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 (https://arduino.stackexchange.com/questions/1758/whats-the-most-accurate-way-to-time-stamp-analogread-data)

5/10/2018:
- I FINALLY GOT IT WORKING AND EVERYTHING
- I ditched using the continuous rotation servo in favor of a regular servo so I could more effectively use Charles Grassin’s code
- Implemented this both in the WeLab (which worked) and then implemented it outside in the outdoor classroom
- I copied the data (Using command + A and then command + C) from the serial monitor into a text file and then sent these along to Wes to plot in python
- Wes plotted these and the data are BEAUTIFUL!

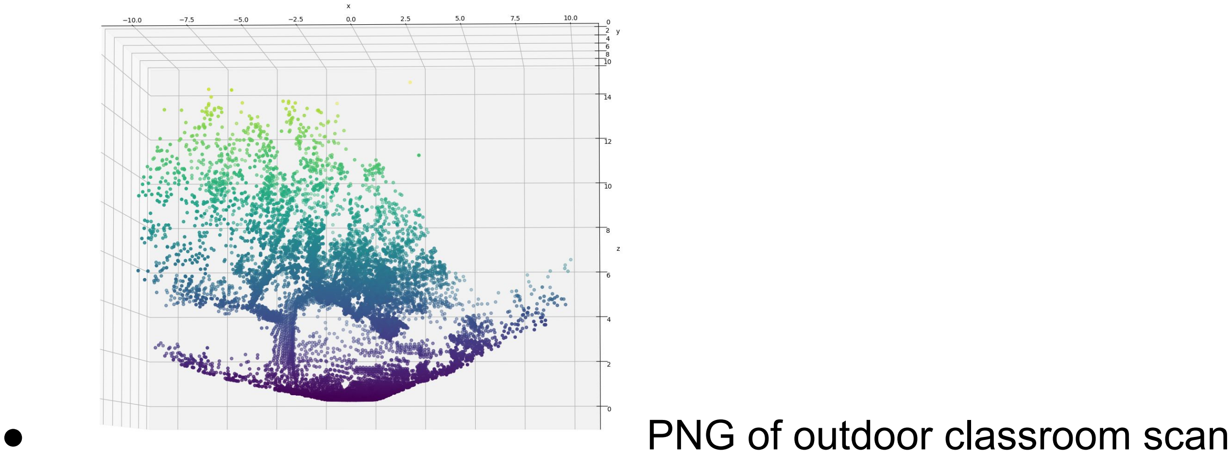
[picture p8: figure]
● PNG of outdoor classroom scan
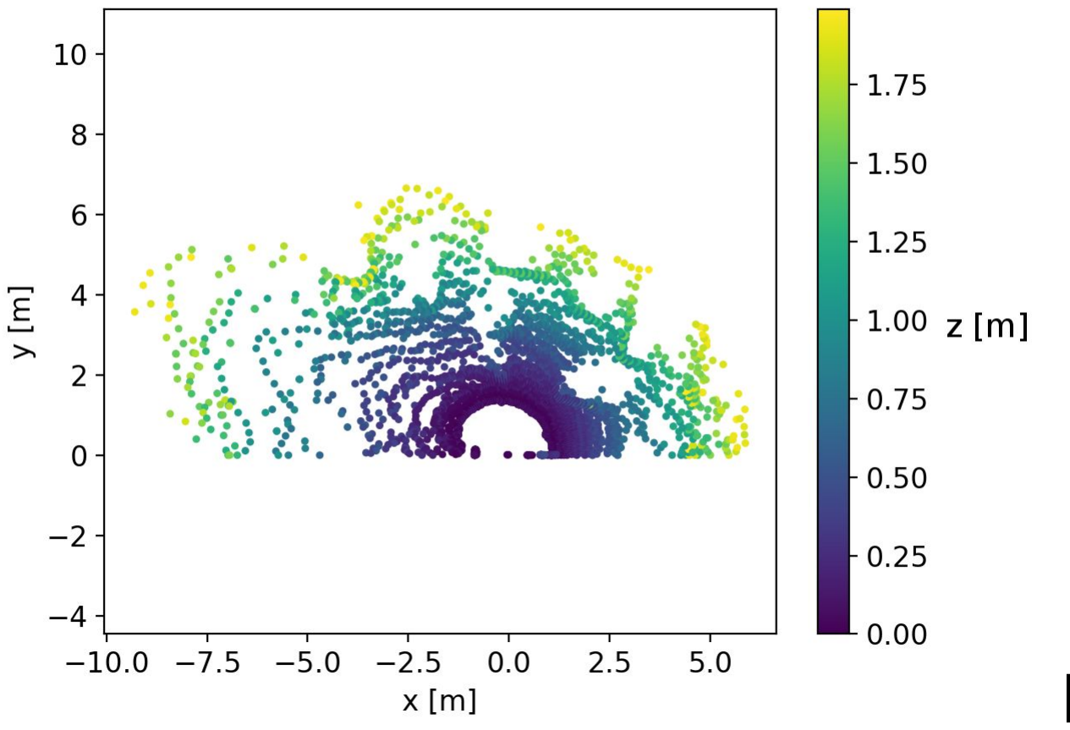
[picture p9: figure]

- PNG of top-down view, viewed below 2 m (to avoid tree branches

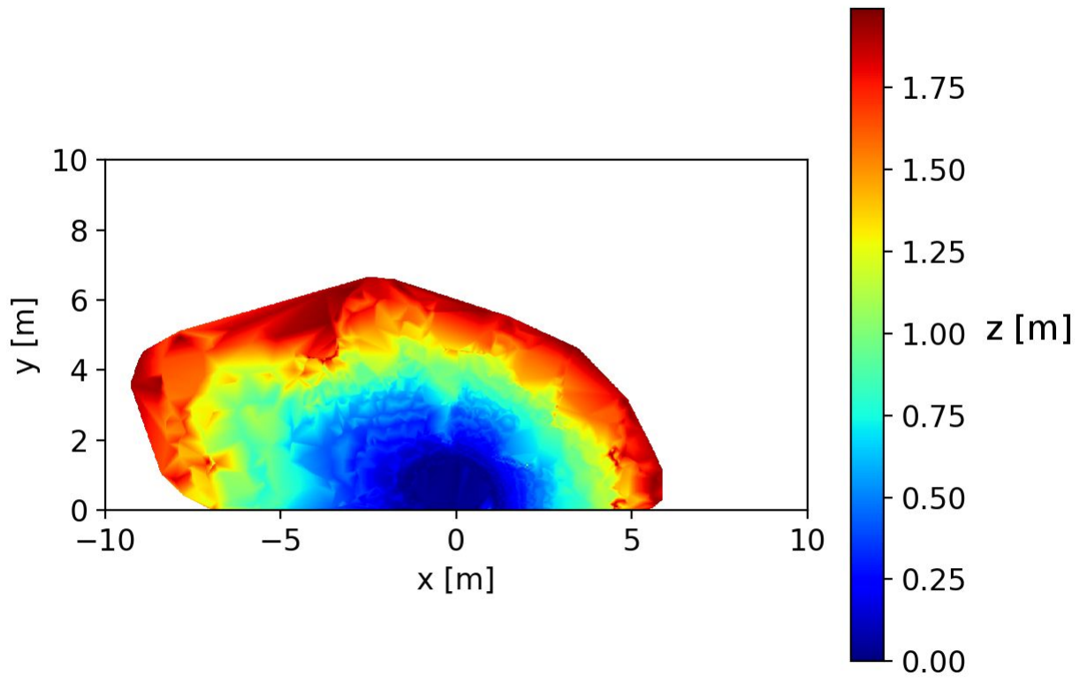
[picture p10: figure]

- PNG of DEM constructed from the above top down view

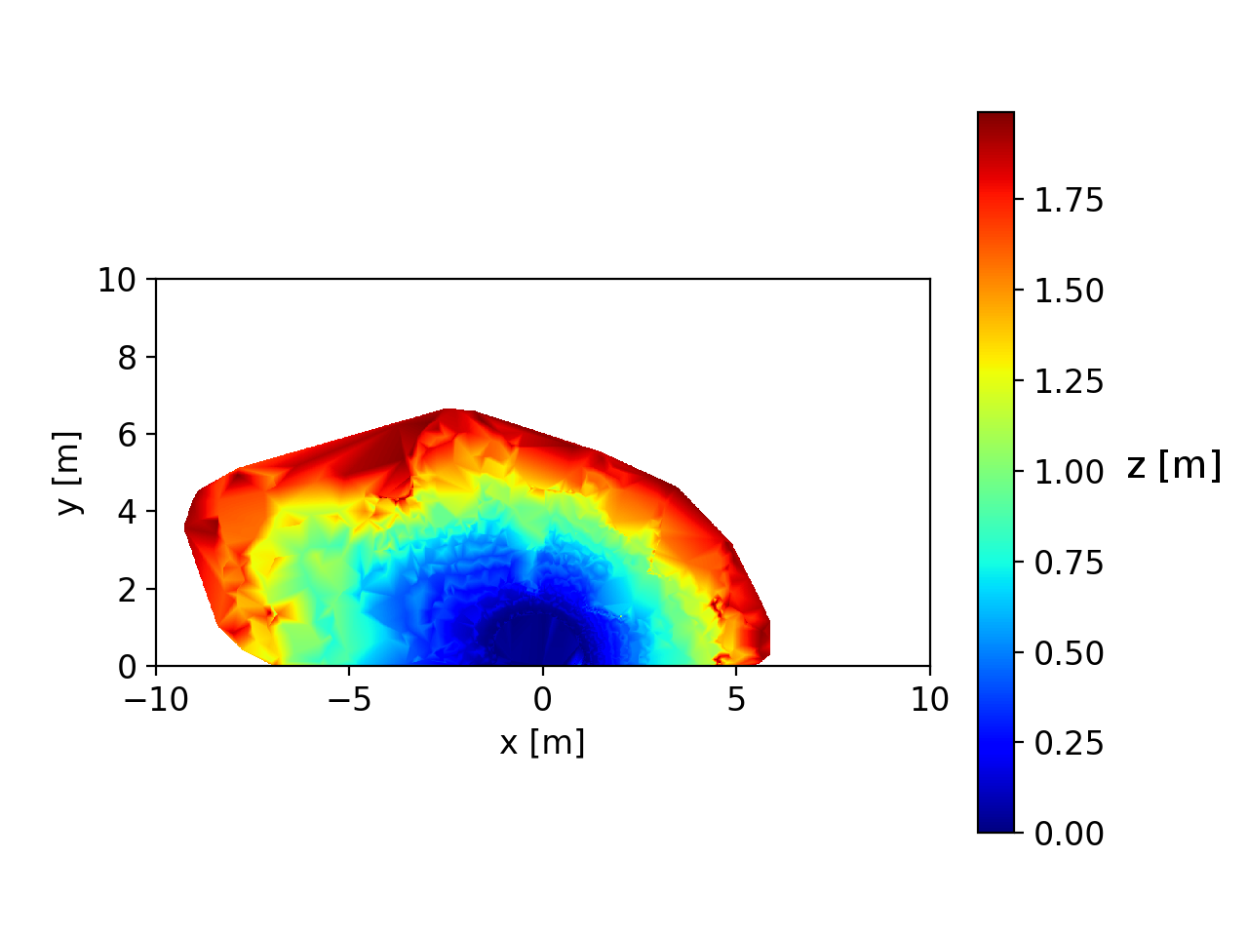
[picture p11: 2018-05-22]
plot-lidar-cloud/scout_lidar_undertree_dem.png

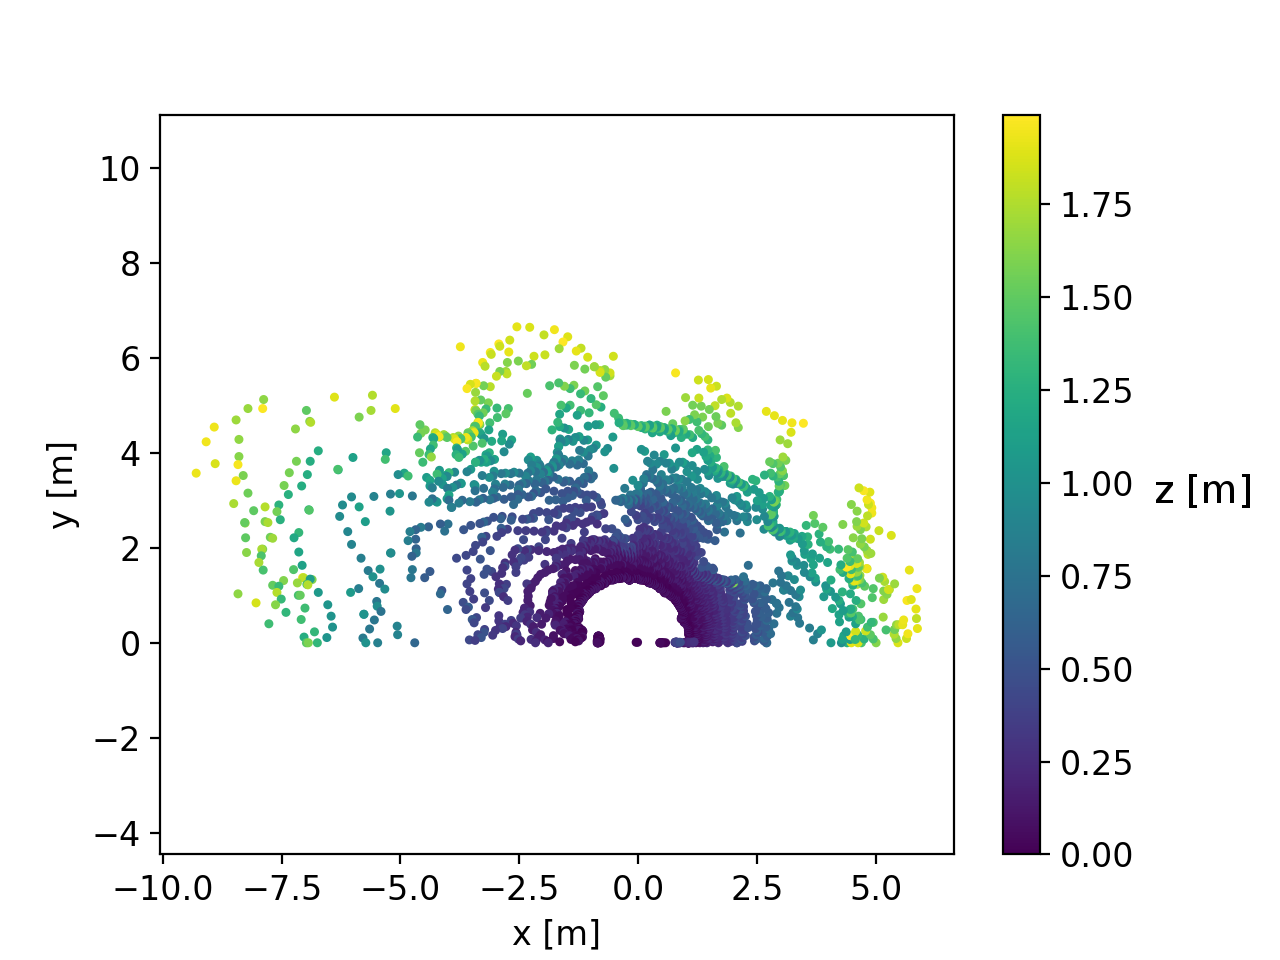
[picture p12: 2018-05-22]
plot-lidar-cloud/scout_lidar_undertree_cloud.png

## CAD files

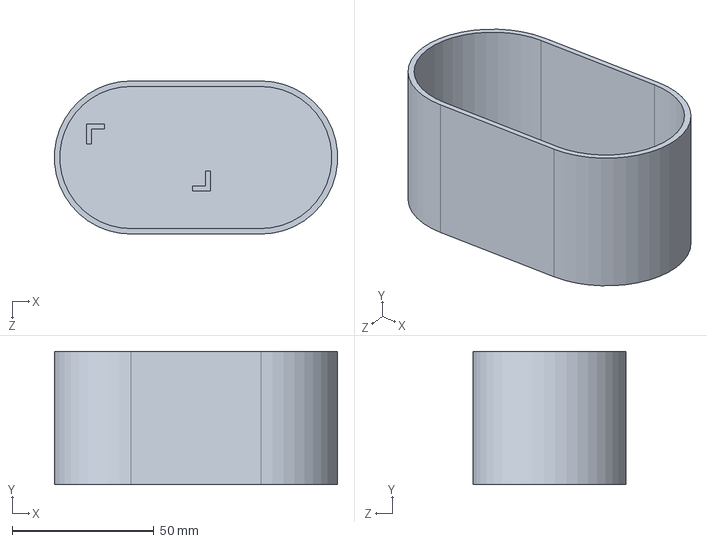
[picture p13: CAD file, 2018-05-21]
LMI_mount_SolidWorks/LIDAR_base_housing.SLDPRT
99.8 x 47.0 x 54.0 mm

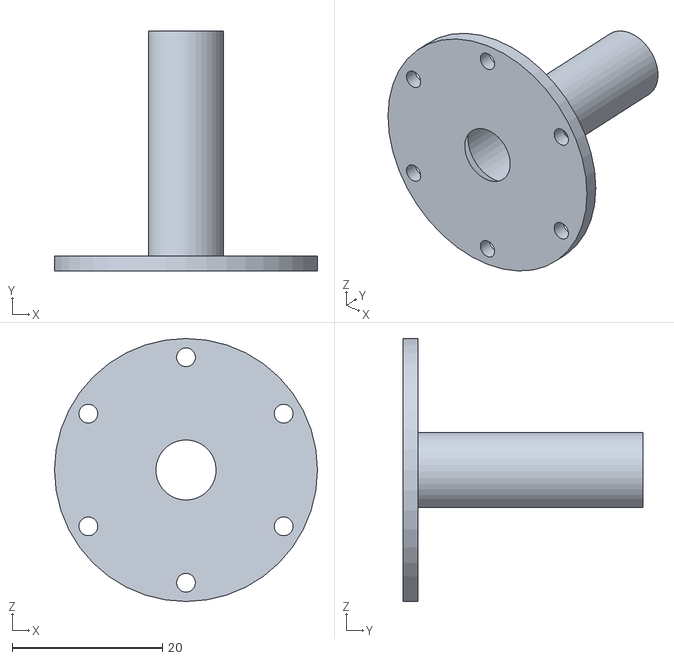
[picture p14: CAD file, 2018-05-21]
LMI_mount_STL/LIDAR_mount_bracket_bottom.stl
35.0 x 32.0 x 35.0

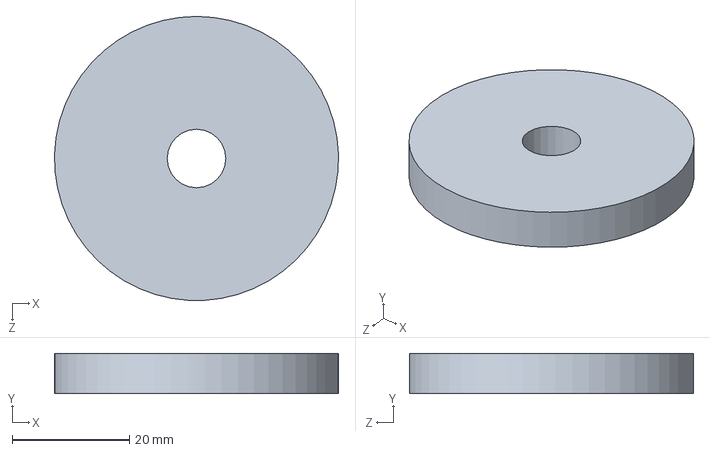
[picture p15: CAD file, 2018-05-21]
LMI_mount_SolidWorks/LIDAR_Gear_proxy_2.SLDPRT
48.5 x 6.86 x 48.5 mm

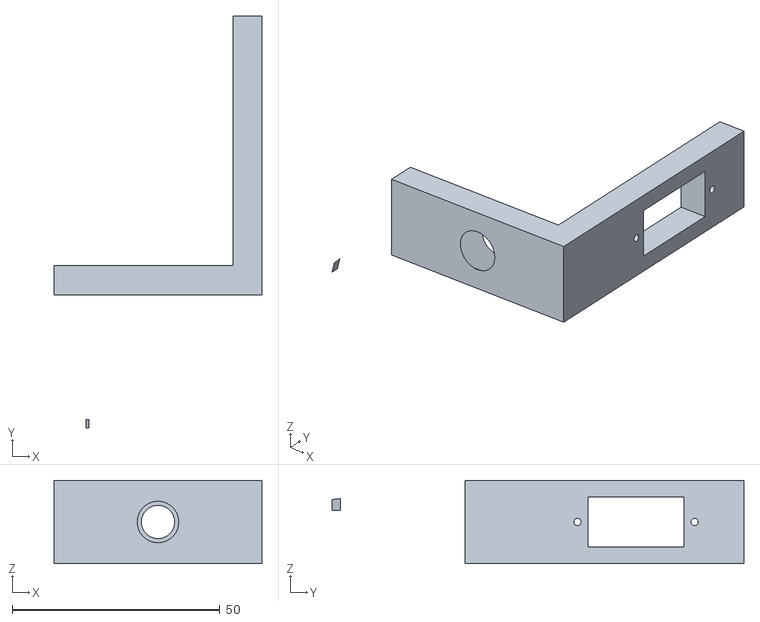
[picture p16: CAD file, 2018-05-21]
LMI_mount_STL/LIDAR_mount_bracket_top.stl
50.0 x 99.0 x 20.0

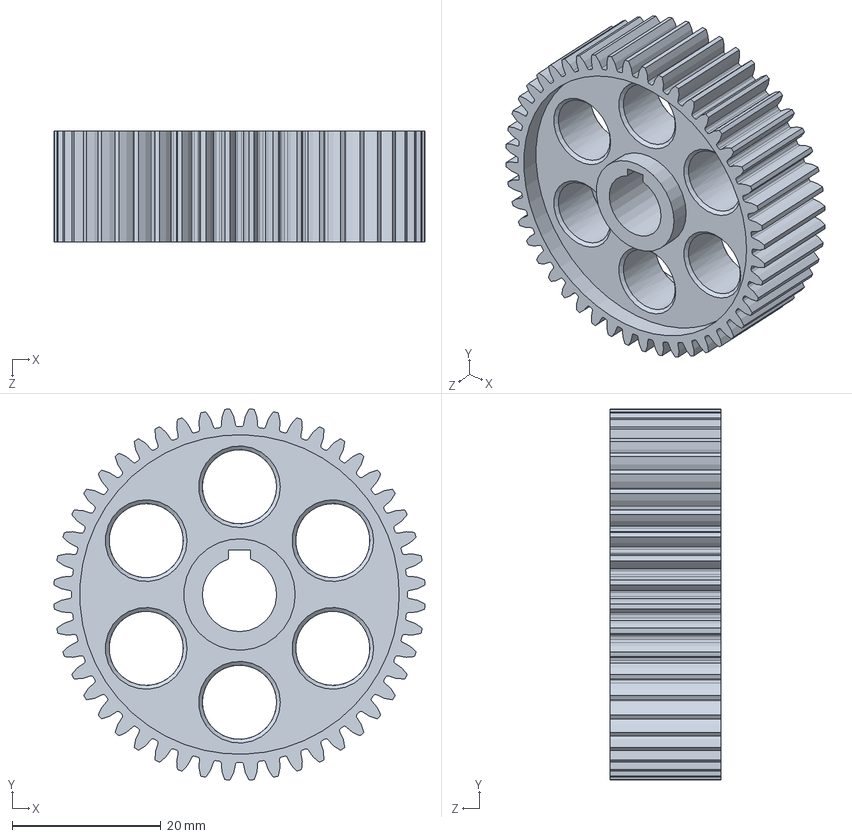
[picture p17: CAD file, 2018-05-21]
LMI_mount_SolidWorks/LIDAR_gear_proxy.SLDPRT
49.9 x 49.9 x 15.0 mm

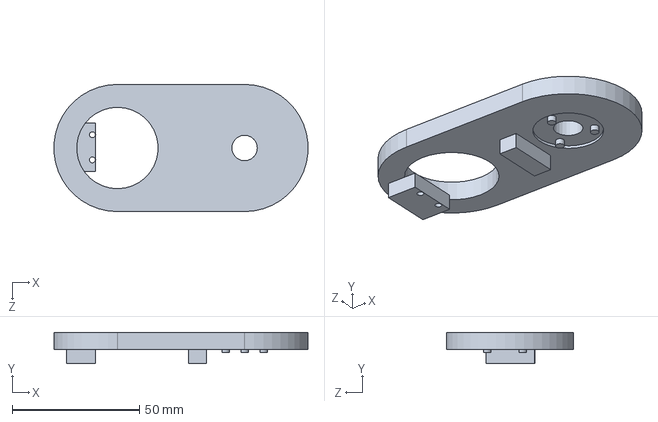
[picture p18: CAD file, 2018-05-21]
LMI_mount_SolidWorks/LIDAR_base.SLDPRT
99.9 x 12.4 x 50.0 mm

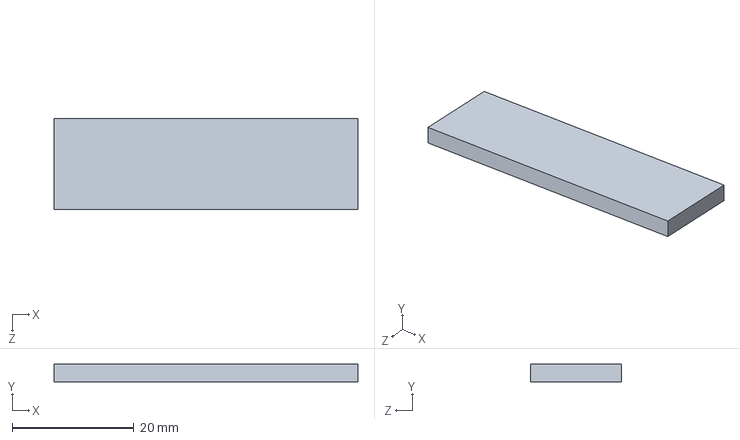
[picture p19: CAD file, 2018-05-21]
LMI_mount_SolidWorks/LIDAR_mount_side4.SLDPRT
50.0 x 2.95 x 15.0 mm

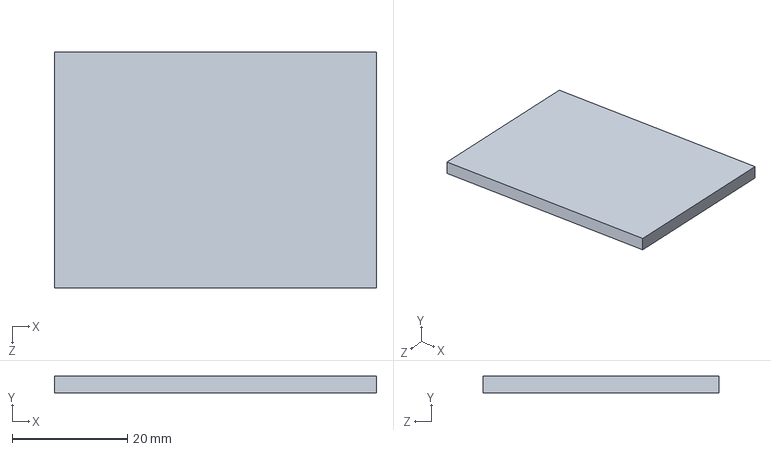
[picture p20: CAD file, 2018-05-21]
LMI_mount_SolidWorks/LIDAR_mount_side2.SLDPRT
55.9 x 2.95 x 41.0 mm

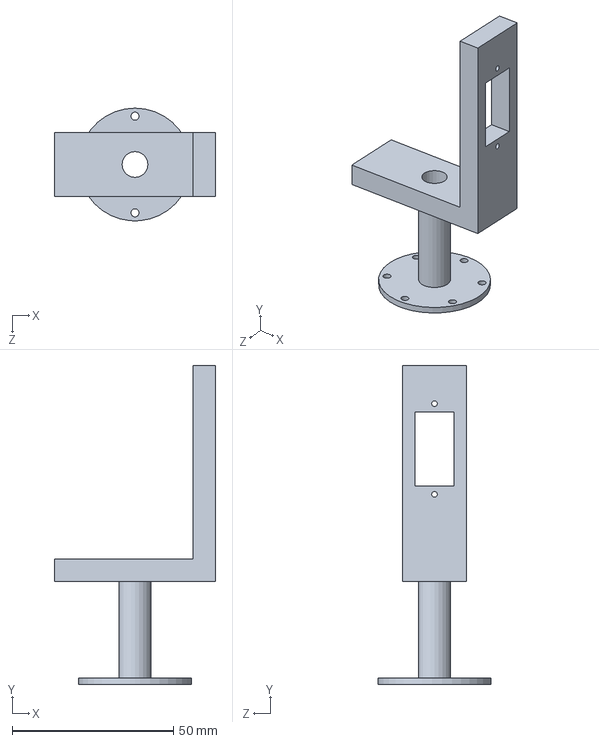
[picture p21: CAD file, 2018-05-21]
LMI_mount_SolidWorks/LIDAR_mount_bracket.SLDPRT
50.0 x 99.0 x 35.0 mm

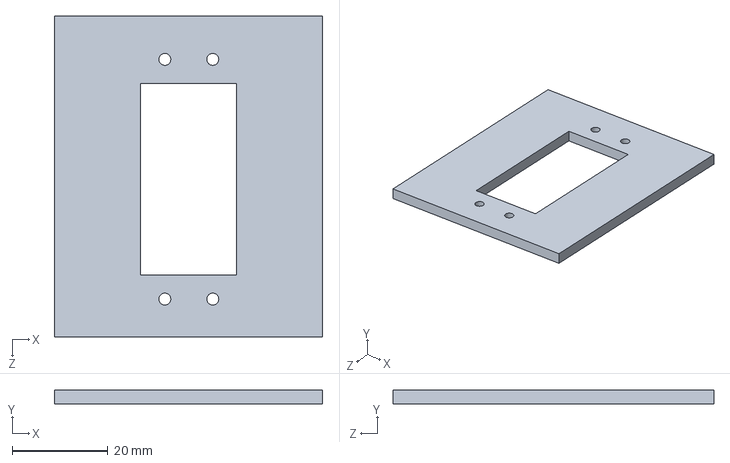
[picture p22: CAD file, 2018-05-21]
LMI_mount_SolidWorks/LIDAR_mount_servo_mount.SLDPRT
55.9 x 2.95 x 66.9 mm

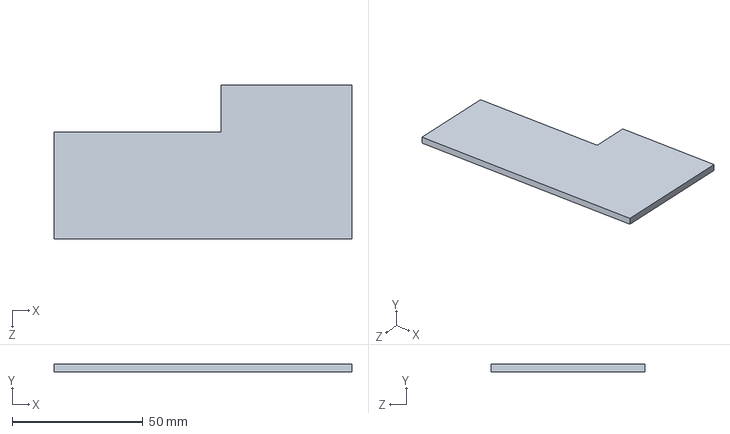
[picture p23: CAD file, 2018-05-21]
LMI_mount_SolidWorks/LIDAR_mount_side1.SLDPRT
113.9 x 2.95 x 59.0 mm

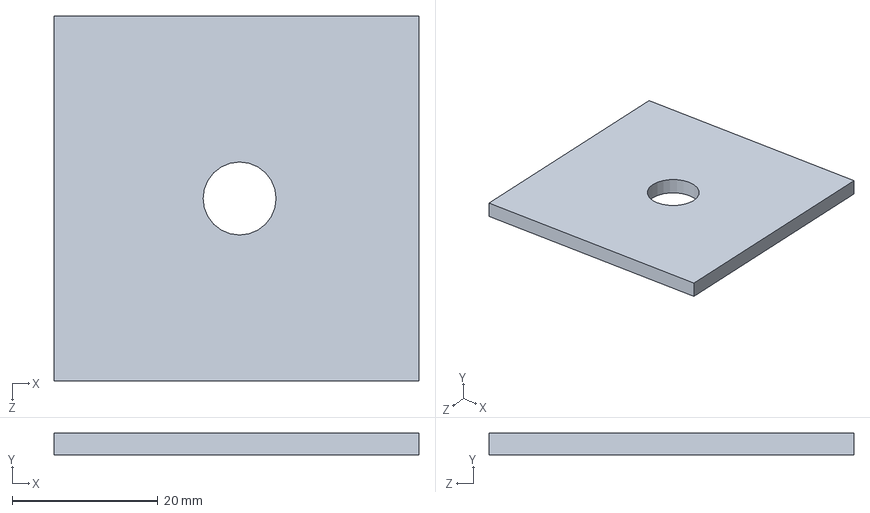
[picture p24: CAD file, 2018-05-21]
LMI_mount_SolidWorks/LIDAR_mount_wirefeed_location.SLDPRT
50.0 x 2.95 x 50.0 mm

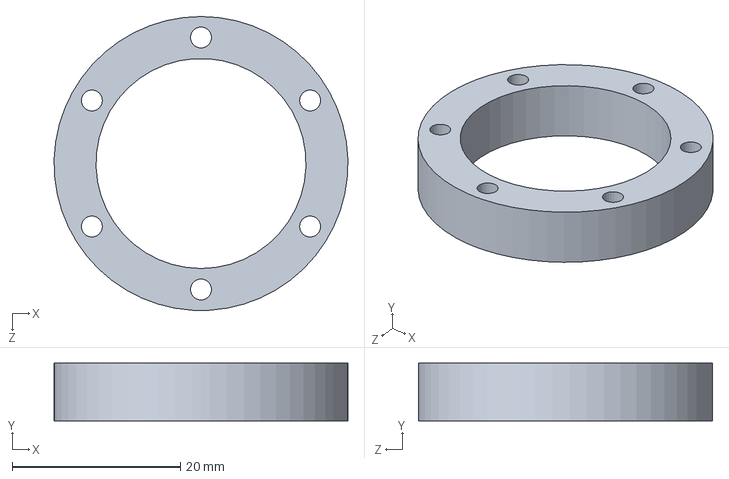
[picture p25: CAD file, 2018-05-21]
LMI_mount_SolidWorks/LIDAR_mount_mast_base.SLDPRT
35.0 x 6.86 x 35.0 mm

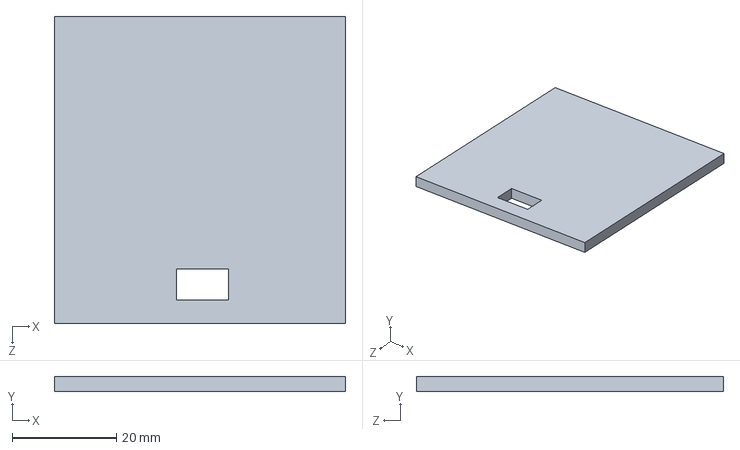
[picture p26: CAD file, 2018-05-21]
LMI_mount_SolidWorks/LIDAR_mount_side3.SLDPRT
55.9 x 2.95 x 59.0 mm

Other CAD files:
LMI_mount_SolidWorks/LIDAR_mount_side1_mirror.SLDPRT
LMI_mount_SolidWorks/LIDAR_mount_base.SLDPRT
LMI_mount_SolidWorks/LIDAR_mount_LIDAR_mount.SLDPRT
LMI_mount_DXF/LIDAR_mount_base.DXF
LMI_mount_DXF/LIDAR_mount_mast_base.DXF
LMI_mount_DXF/LIDAR_mount_servo_mount.DXF
LMI_mount_DXF/LIDAR_mount_side1.DXF
LMI_mount_DXF/LIDAR_mount_side1_mirror.DXF
LMI_mount_DXF/LIDAR_mount_side2.DXF
LMI_mount_DXF/LIDAR_mount_side3.DXF
LMI_mount_DXF/LIDAR_mount_side4.DXF
LMI_mount_DXF/LIDAR_mount_wirefeed_location.DXF
LMI_mount_STL/LIDAR_mount_LIDAR_mount.STL
LMI_mount_STL/LIDAR_mount_bracket.STL
LMI_mount_STL/LIDAR_wirefeed.STL
LMI_mount_SolidWorks/LIDAR_wirefeed.SLDPRT

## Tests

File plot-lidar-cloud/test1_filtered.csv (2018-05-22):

x | y | z
58 | 0 | 0
57 | 0 | 1
55 | 0 | 1
58 | 0 | 3
55 | 0 | 3
58 | 0 | 5
70 | 0 | 7
78 | 0 | 9
79 | 0 | 11
85 | 0 | 13
93 | 0 | 16
99 | 0 | 19
97 | 0 | 20
98 | 0 | 22
97 | 0 | 24
96 | 0 | 25
95 | 0 | 27
95 | 0 | 29
97 | 0 | 31
323 | 0 | 111
323 | 0 | 117
321 | 0 | 123
319 | 0 | 129
316 | 0 | 134
315 | 0 | 140
311 | 0 | 145
310 | 0 | 151
308 | 0 | 157
305 | 0 | 162
303 | 0 | 168
302 | 0 | 174
299 | 0 | 179
297 | 0 | 186
296 | 0 | 192
293 | 0 | 197
290 | 0 | 203
288 | 0 | 209
289 | 0 | 217
286 | 0 | 223
284 | 0 | 230
281 | 0 | 236
277 | 0 | 241
279 | 0 | 251
275 | 0 | 257
274 | 0 | 264
270 | 0 | 270
267 | 0 | 276
262 | 0 | 281
258 | 0 | 287
248 | 0 | 286
249 | 0 | 297
252 | 0 | 311
238 | 0 | 304
226 | 0 | 301
241 | 0 | 332
231 | 0 | 330
220 | 0 | 327
210 | 0 | 323
200 | 0 | 320
166 | 0 | 277
141 | 0 | 245
136 | 0 | 245
128 | 0 | 241
121 | 0 | 237
114 | 0 | 235
109 | 0 | 234
105 | 0 | 236
103 | 0 | 243
99 | 0 | 246
98 | 0 | 256
93 | 0 | 257
85 | 0 | 249
83 | 0 | 255
87 | 0 | 285
82 | 0 | 286
76 | 0 | 284
76 | 1 | 285
81 | 1 | 283
86 | 1 | 284
91 | 1 | 280
97 | 1 | 281
92 | 1 | 253
97 | 1 | 253
100 | 1 | 248
102 | 1 | 241
105 | 1 | 237
109 | 1 | 235
114 | 2 | 235
120 | 2 | 236
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

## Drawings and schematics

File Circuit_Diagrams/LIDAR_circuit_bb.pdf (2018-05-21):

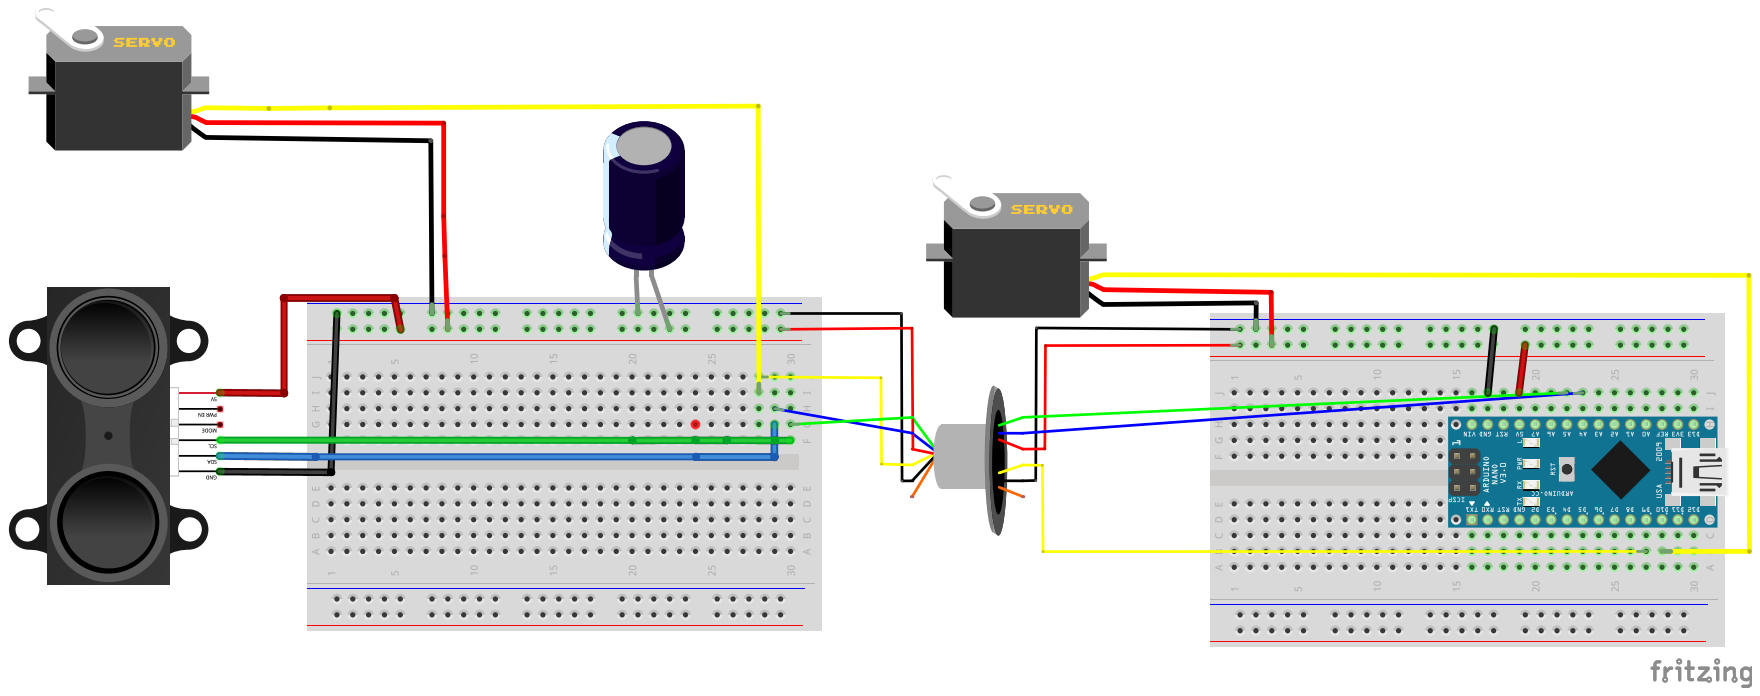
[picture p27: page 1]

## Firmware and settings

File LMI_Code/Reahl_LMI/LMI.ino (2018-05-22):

/* -----------------------------------------------------------------------------------------
Lidar Mapping Instrument (LMI; pronounced "Lemmy")
  
  By Jocelyn Reahl '19, Wellesley College
  
  Adapted from LidarTurret.ino by Charles Grassin
    Code and project found here: http://www.charleslabs.fr/en/project-3D+Lidar+Scanner
  
  Professor Wes Watters
    ASTR 202: Hands-On Planetary Exploration; Spring 2018

--------------------------------------------------------------

Some Considerations:
  The Altitude (ALT) motor can only reach an angle of 75°
  The Azimuth (AZ) motor can only rotate 180° (as of 5/21/2018 it is a standard servo motor)
    Future paths for the Azimuth motor involve implementing either:
      Parallax Feedback 360°™ continuous rotation servo motor with feedback pin (aka encoder) @ pin A0
        or
      Standard continuous rotation servo with timestamps
        or
      Bidirectional Stepper motor with 0.9° full step increments

--------------------------------------------------------------

Instructions for Use (with already constructed LMI):
  1) Download the Arduino IDE: https://www.arduino.cc/en/Main/Software
    (you've probably already completed this step)
    
  2) Download the following libraries (Make sure to reboot the IDE when you download them):
    How to Download Libraries: https://learn.sparkfun.com/tutorials/installing-an-arduino-library
    Servo.h (Runs your servos; typically already comes w/IDE): https://github.com/arduino-libraries/Servo
    Wire.h (Allows Arduino to communicate w/I2C devices; typically already comes w/IDE): https://github.com/esp8266/Arduino/tree/master/libraries/Wire
    LIDARLite.h (Allows you to run your LIDARLite v3): https://github.com/garmin/LIDARLite_v3_Arduino_Library
    
  3) Plug in LMI's attached USB cord to your computer
  
  4) Check "Tools" tab on Arduino IDE and check that:
    Board = Arduino Nano
    Processor = ATmega328P
    Port = Something that has "usbserial" in it with a string of letters and numbers after it; nothing with "Bluetooth" in it
      If you are running Mac OS X, you'll need to download FTDI drivers
        Tutorial from SparkFun: https://learn.sparkfun.com/tutorials/how-to-install-ftdi-drivers/mac
        
  5) Click "Upload" (the button on that looks like an arrow pointing to the right)
  
  6) Open up Serial Monitor (button is on top right; looks like a magnifying glass) and make sure it's set to 115200 baud
  
  7) Data! Columns from left to right: x, y, and z coordinates; these are computed by the program from Range (r), theta, and phi angles.

  8) When scanner reaches the end of its scanning cycle, deselect "Autoscroll" on the Serial Monitor and hit Control (or "Command" if you're using Mac) + A to select all the data in the window

  9) Copy these data into a text file and save it.

  10) Plot these data in your favorite 3D plotting software after removing "> nack" values from the data set (these are random "hiccup" values)

  Can also use this program in conjunction with LidarViewer by Charles Grassin, which uses the Processing program
  This program is a great resource for demonstration and presentation, but don't expect to be able to save these results
    Download Processing here: https://processing.org/download/
    After uploading the Arduino code, upload the Processing LidarViewer code
    DO NOT open the Serial Monitor when you are using the Processing code - it's using the serial monitor and it'll get confused if both Processing and the serial monitor are open

-----------------------------------------------------------
General troubleshooting (Future Users: please add any other troubleshooting solutions you have! - Jocelyn Reahl)

"When in doubt, reboot!" - Jocelyn Reahl's dad

Still seeing the "Bluetooth" ports even after downloading FTDI drivers (this only applies if you've gotten this to work before)
  Reboot Arduino and reopen with LMI's USB cord UNPLUGGED

LMI stopped scanning in the middle of its scan! What the heck?!
  Check the Serial Monitor; if the last measurement was "> nack" then it got stuck there instead of recovering. Upload an empty Arduino sketch, wait for ~30 sec, and then re-upload this sketch.

(If using a continuous rotation servo for the Azimuth motor)
I told my continuous rotation servo to move from x degree to y degree in a for loop and it's just moving around like crazy! What did I do wrong?
  Continuous rotation servos, while able to run on the Servo.h library, interpret Servo.write(0) as rotating at full speed in one direction, Servo.write(180) as moving at full speed in the other direction, and Servo.write(90) as stationary
          
----------------------------------------------------------------------------------------- */
//Include Libraries downloaded in Step 2:
#include <Servo.h>
#include <Wire.h>
#include <LIDARLite.h>

#define DELAY_BETWEEN_SAMPLES 100 //Delay between each sample to avoid mechanical wobble

//Defining the size of the steps that AZ/ALT make in degrees (1 = full resolution); change the number after AZ_STEP/ALT_STEP in order to change the step size
#define AZ_STEP 1
#define ALT_STEP 1
#define MATH_PI 3.1415f //defining what pi is (for use in later calculations)

//Variables
LIDARLite myLidarLite;
Servo servoAz,servoAlt; //defines the Azimuth servo (servoAz) and Altitude servo (servoAlt)
char s[15];
int azAngle,altAngle; //defines the angles from the Alt/Az servos as integers for use in later calculations (the units for these angles are in radians)
int x,y,z,r; //sets x, y, z, and r as integers for use in later calculations
float theta,phi; //sets theta and phi as numbers that can have decimals for use in calculations that convert azAngle and altAngle from radians to degrees

void setup() {
  // Initialize Serial Monitor to display distance readings
  Serial.begin(115200); //Set serial monitor to 115200 baud

  //Servo initialization
  servoAz.attach(9); //attaches the Azimuth servo to digital pin 9 on Arduino Nano (D9)
  servoAlt.attach(10); //attaches the Altitude servo to digital pin 10 on Arduino Nano (D10)
  
  //Set Alt and Az servos to starting position 0°
  servoAz.write(0); 
  servoAlt.write(0);

  //Lidar Lite v3 initialization 
  //(details on the different settings can be found in the "GetDistanceI2C" example that comes with the LIDARLite library; using 0 (standard setting) is probably best for our purposes)
  myLidarLite.begin(0, true);
  myLidarLite.configure(0);
}

void loop() {
  delay(5000); //delay 5 seconds so you can open the Serial Monitor or start running the Processing program
  //Sweep Az servomotor
  for (azAngle = 0; azAngle <= 180; azAngle += AZ_STEP) //Don't change this unless you're using a different Az motor
  {
    servoAz.write(azAngle);
    
    //Sweep Alt servomotor. The direction depends on the current directory
    if(altAngle < 23) //This is the max altAngle that is swept divided by 2 (and rounded up for numbers ending in .5); note that the max altAngle is 75)
    {
      for (altAngle = 0; altAngle <= 45;altAngle+= ALT_STEP){
        servoAlt.write(altAngle);
        sendMeasurement();
      }
    } else {
      for (altAngle = 45; altAngle >= 0;altAngle-= ALT_STEP){
        servoAlt.write(altAngle);
        sendMeasurement();
      }
    }
  }
}

// Function to acquire, convert and send the measurement.
void sendMeasurement(){
  delay(DELAY_BETWEEN_SAMPLES);
  
  // Compute spherical coordinates
  r = myLidarLite.distance(false);
  theta = (float)azAngle * PI / 180.0f;
  phi = (float)altAngle * PI / 180.0f;

  // Convert and send them to the Serial Monitor
  sprintf(s,"%d %d %d\n\0",(int)(r*cos(phi)*cos(theta)),(int)(r*cos(phi)*sin(theta)),(int)(r*sin(phi)));
  Serial.print(s);
}

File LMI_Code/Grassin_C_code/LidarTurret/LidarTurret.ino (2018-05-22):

#include <Servo.h>
#include <Wire.h>
#include <LIDARLite.h>

//Delay between each sample to avoid mechanical wobble
#define DELAY_BETWEEN_SAMPLES 100
//Size of the steps of YAW/PITCH in degrees (1 = full res)
#define YAW_STEP 2
#define PITCH_STEP 2
#define MATH_PI 3.1415f

//Variables
LIDARLite myLidarLite;
Servo servoYaw,servoPitch;
char s[15];
int yawAngle,pitchAngle;
int x,y,z,r;
float theta,phi;

void setup() {
  // Initialize serial connection to display distance readings
  Serial.begin(115200); 

  //Servo init
  servoYaw.attach(10);
  servoPitch.attach(11);

  //Lidar Lite v3 init
  myLidarLite.begin(0, true);
  myLidarLite.configure(0);
}

void loop() {
  delay(5000);
  //Sweep Yaw servomotor
  for (yawAngle = 0; yawAngle <= 180; yawAngle += YAW_STEP) {
    servoYaw.write(yawAngle);
    
    //Sweep Pitch servomotor. The direction depends on the current directory
    if(pitchAngle < 90){
      for (pitchAngle = 0; pitchAngle <= 180;pitchAngle+= PITCH_STEP){
        servoPitch.write(pitchAngle);
        sendMeasurement();
      }
    } else {
      for (pitchAngle = 180; pitchAngle >= 0;pitchAngle-= PITCH_STEP){
        servoPitch.write(pitchAngle);
        sendMeasurement();
      }
    }
  }
}

// Function to acquire, convert and send the measurement.
void sendMeasurement(){
  delay(DELAY_BETWEEN_SAMPLES);
  
  // Get spherical coordinates
  r = myLidarLite.distance(false);
  theta = (float)yawAngle * PI / 180.0f;
  phi = (float)pitchAngle * PI / 180.0f;

  // Convert and send them
  sprintf(s,"%d %d %d\n\0",(int)(r*cos(phi)*cos(theta)),(int)(r*cos(phi)*sin(theta)),(int)(r*sin(phi)));
  Serial.print(s);
}
